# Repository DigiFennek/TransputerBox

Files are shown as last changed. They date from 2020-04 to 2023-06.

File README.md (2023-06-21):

# TransputerBox
This is the DosBox based TransputerBox

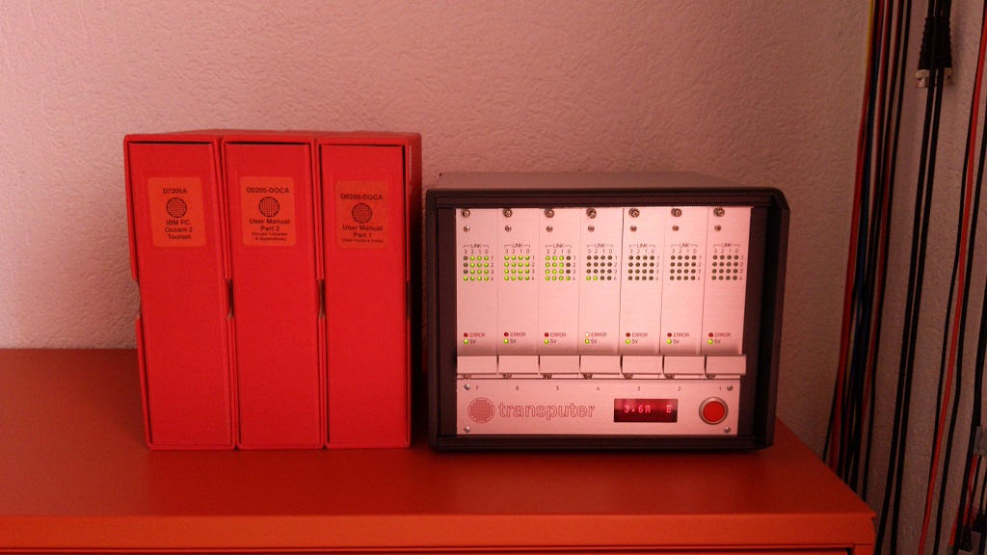
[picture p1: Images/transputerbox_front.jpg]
TransputerBox Front


The interface is based on a LPC dual-core MPU. The Cortex-M4 is doing USB stuff while the Cortex-M0+ is talking to the IMSC012 Transpuer Link Interface. The MCU is also checking the health status of the power supply and the cooling system.

The host-side is based on a modified version of DOSBox. It emulates the IMSB008 or IMSB004 hardware and connets to the TransputerBox via USB.

Software:
  - DOSBox with USB-Bridge, Windows 10, Visual Studio 2019: [Link](https://github.com/DigiFennek/TransputerBox/tree/master/Visual%20Studio)
  - USB-Interface, based on NXP's LPC54114, MCUXPresso IDE v11: [Link](https://github.com/DigiFennek/TransputerBox/tree/master/MCUXpresso)
  - CPLD for the fancy Link-Leds, Lattice M4A5-64/32-10VC, ispLever Classic: [Link](https://github.com/DigiFennek/TransputerBox/tree/master/ispLEVER%20Classic/linkled)
  
Hardware:
  - Module for 4 TRAM's, Eagle Layout Editor: [Link](https://github.com/DigiFennek/TransputerBox/tree/master/Eagle/TB-4)
  - Backpanel with 7 slots, Eagle Layout Editor: [Link](https://github.com/DigiFennek/TransputerBox/tree/master/Eagle/BB-7)
  - USB Interface with Power Management, Current Sensor and HP-Display, Eagle Layout Editor: [Link](https://github.com/DigiFennek/TransputerBox/tree/master/Eagle/UB-1)
  - SIZE-1 TRAM with 128kB SRAM, Eagle Layout Editor: [Link](https://github.com/DigiFennek/TransputerBox/tree/master/Eagle/TM-2)    
  
Misc
  - Front Panels, www.schaeffer-ag.de "FRONTPLATTEN DESIGNER": [Link](https://github.com/DigiFennek/TransputerBox/tree/master/Schaeffer%20AG)

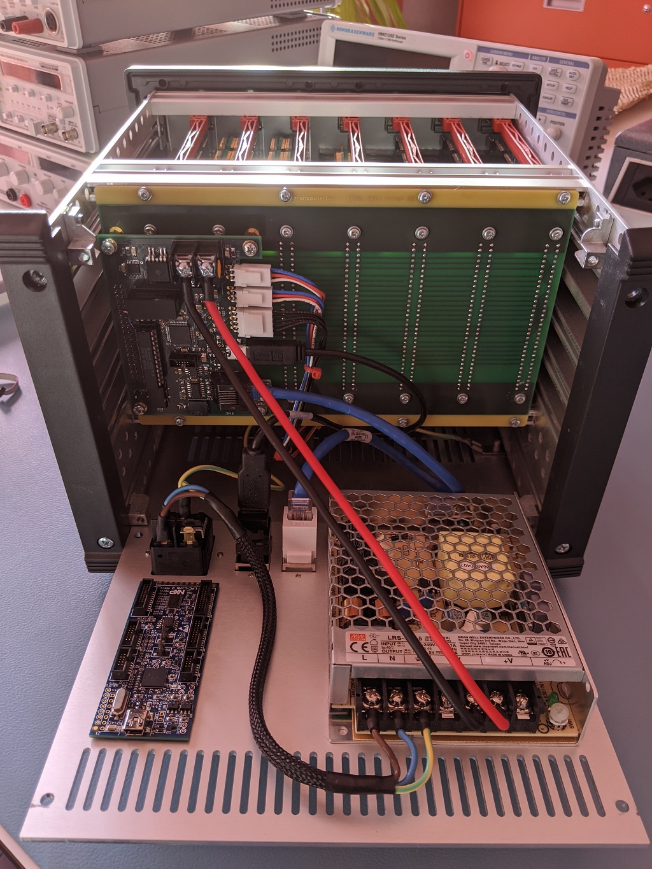
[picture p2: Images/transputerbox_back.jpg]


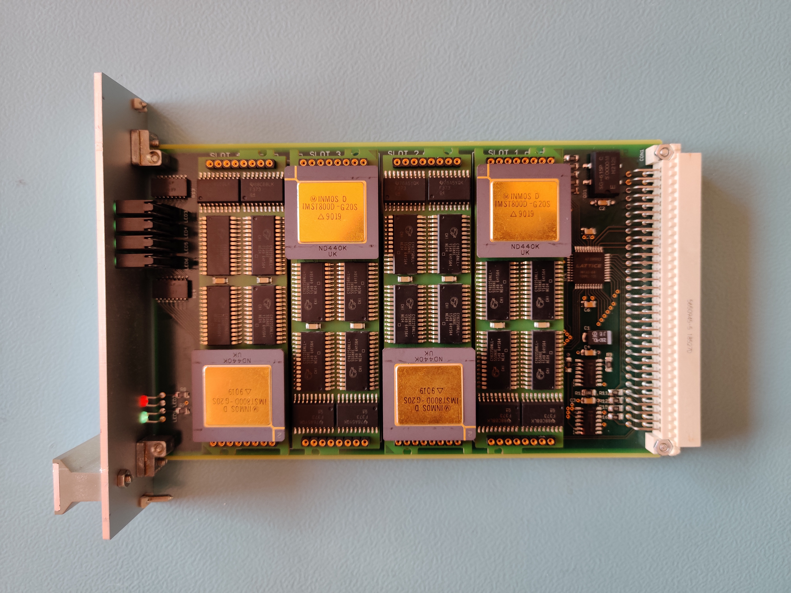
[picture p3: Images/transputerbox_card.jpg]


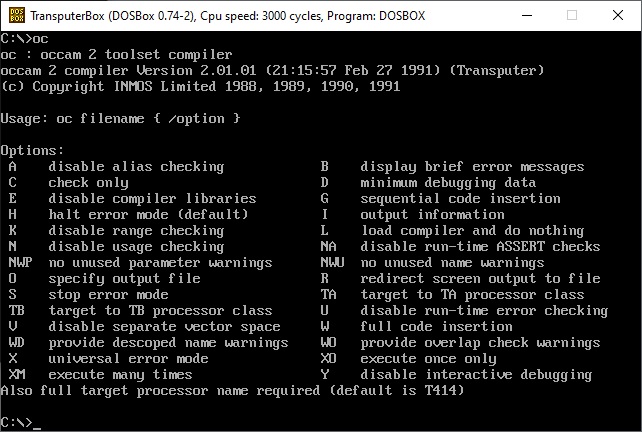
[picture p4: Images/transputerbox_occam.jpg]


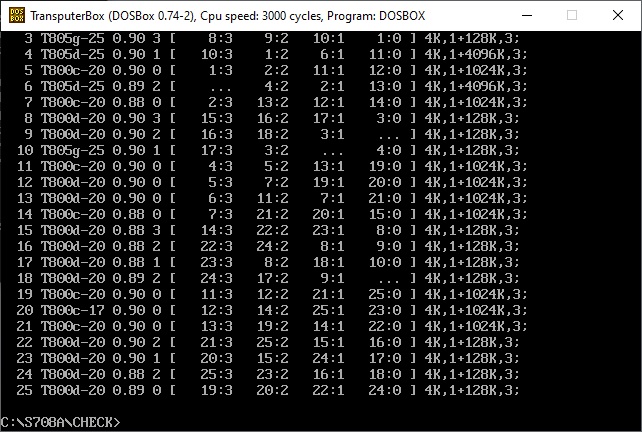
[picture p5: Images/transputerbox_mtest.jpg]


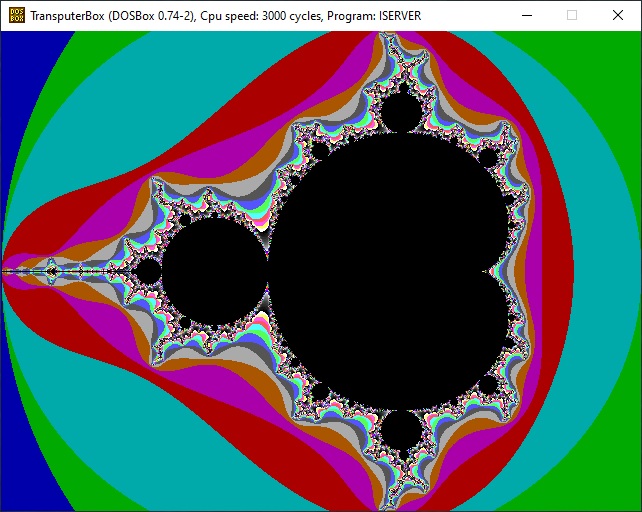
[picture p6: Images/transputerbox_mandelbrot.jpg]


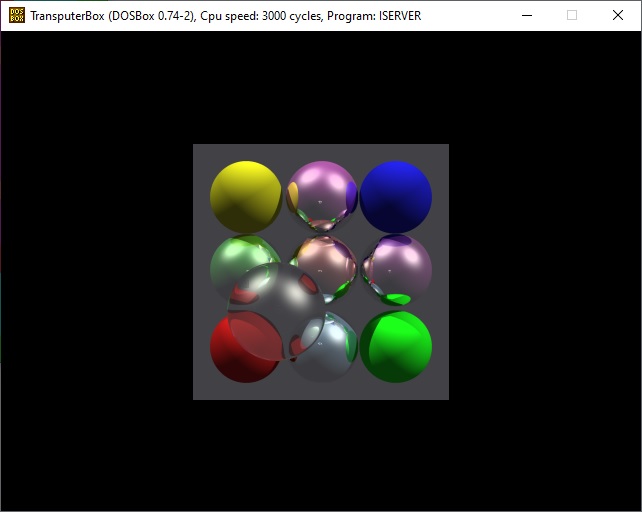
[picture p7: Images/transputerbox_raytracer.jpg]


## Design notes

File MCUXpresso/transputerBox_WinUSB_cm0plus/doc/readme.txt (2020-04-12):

Overview
========
The Multicore Hello World demo application demonstrates how to set up projects for individual
cores on a multicore system. In this demo, the primary core prints the "Hello World from the Primary Core!"
string to the terminal and then releases the secondary core from the reset. The secondary
core toggles an on-board LED indicating that the secondary core is running.

Toolchain supported
===================
- IAR embedded Workbench  8.32.3
- MCUXpresso  11.0.0
- GCC ARM Embedded  8.2.1
- Keil MDK  5.27

Hardware requirements
=====================
- Mini/micro USB cable
- LPCXpresso54114 board
- Personal Computer

Board settings
==============
No special settings are required.

Prepare the Demo
================
1.  Connect a micro USB cable between the PC host and the CMSIS DAP USB port (J7) on the board
2.  Open a serial terminal with the following settings (See Appendix A in Getting started guide for description how to determine serial port number):
    - 115200 baud rate
    - 8 data bits
    - No parity
    - One stop bit
    - No flow control
3.  Download the program to the target board.
4.  Either press the reset button on your board or launch the debugger in your IDE to begin running the demo.

Running the demo
================
The log below shows the output of the hello world multicore demo in the terminal window:
~~~~~~~~~~~~~~~~~~~~~~~~~~~~~~~~~~~
Copy Secondary core image to address: 0x20010000, size: 3280
Starting Secondary core.

Hello World from the Primary Core!

Starting Secondary core.
The secondary core application has been started.

~~~~~~~~~~~~~~~~~~~~~~~~~~~~~~~~~~~
Customization options
=====================

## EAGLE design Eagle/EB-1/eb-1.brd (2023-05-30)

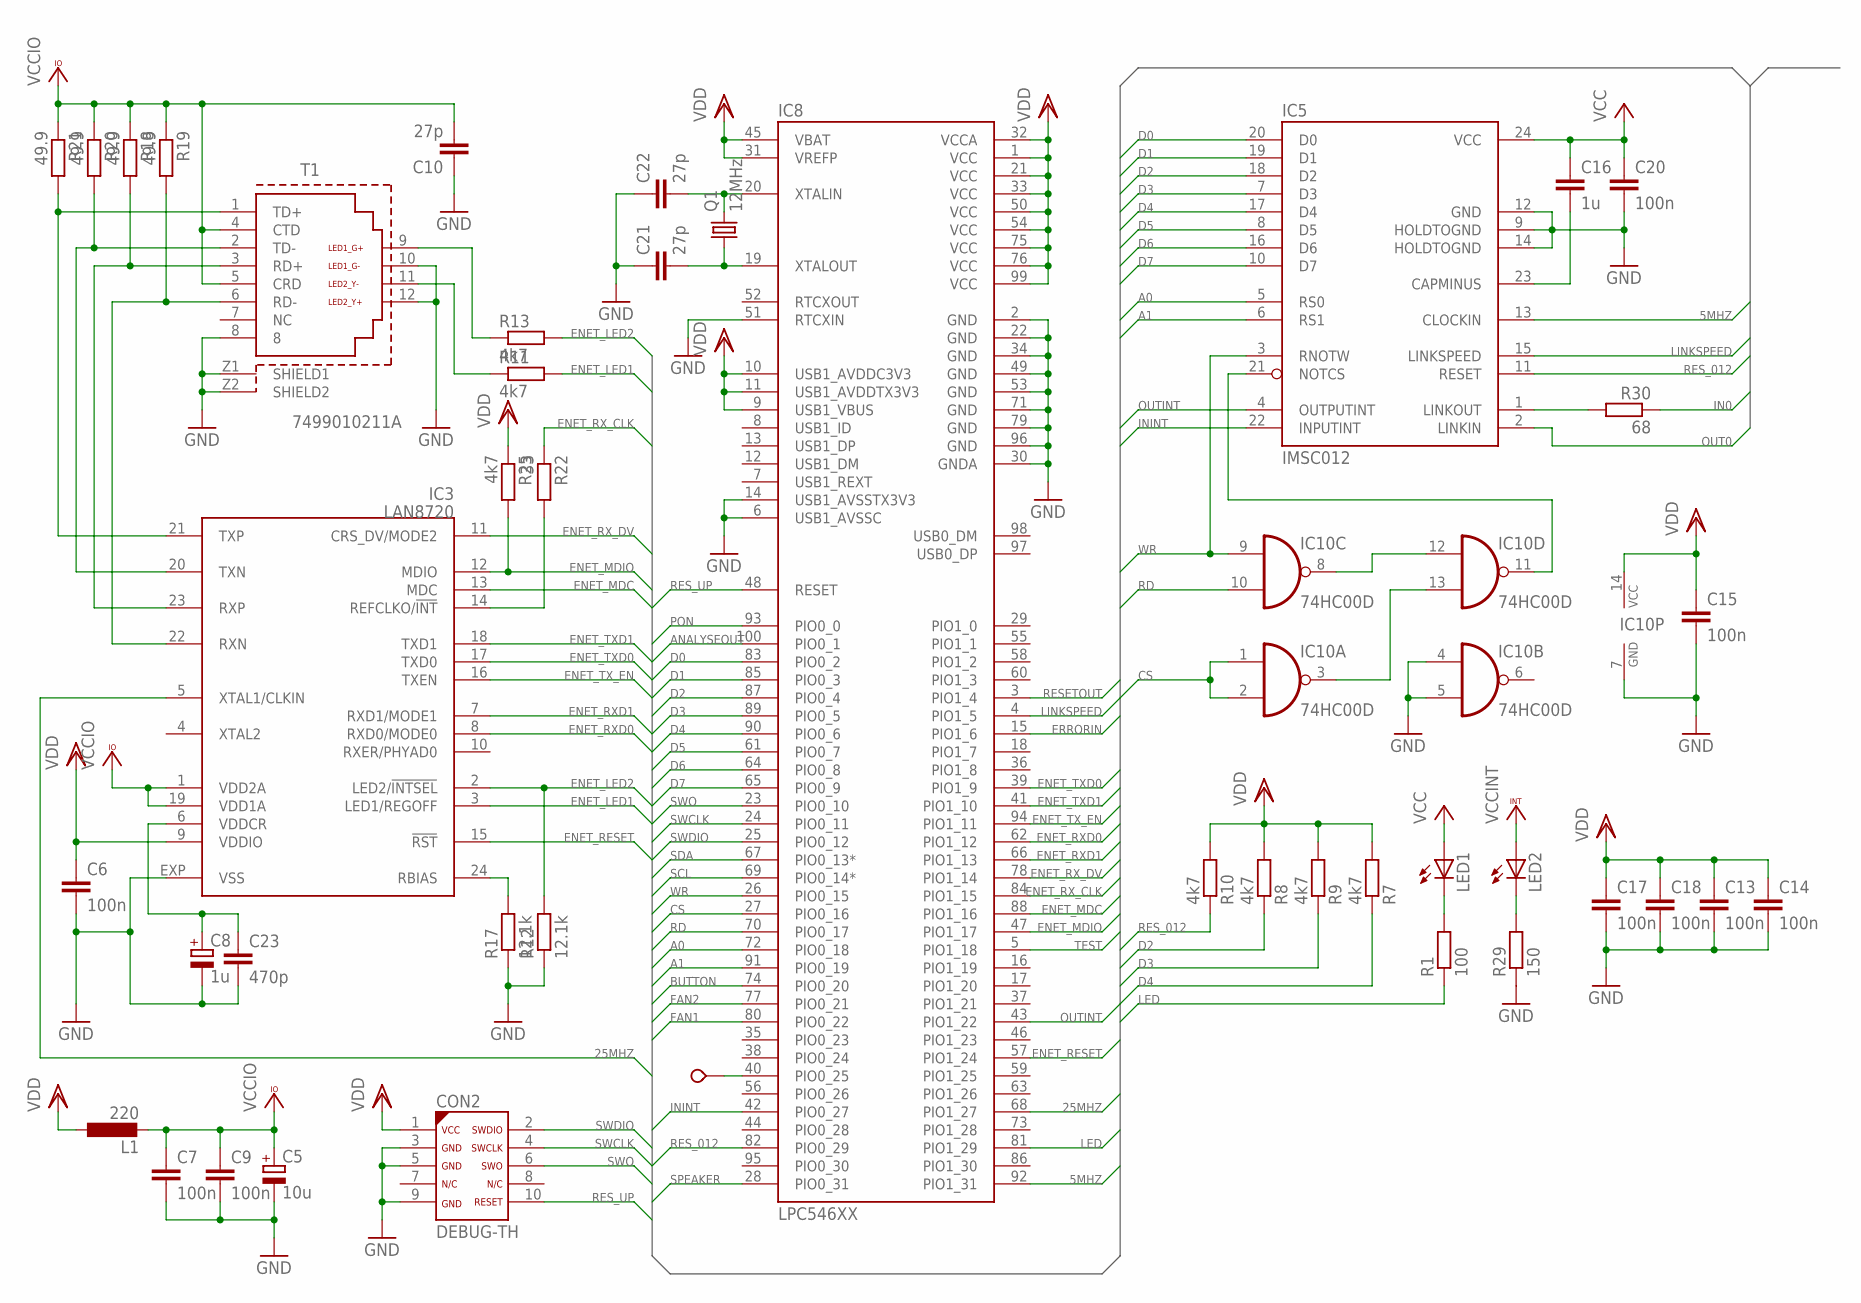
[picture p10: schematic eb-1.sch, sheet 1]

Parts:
C5: 10u; CT3216
C6, C7, C9, C13, C14, C15, C17, C18, C20: 100n; C1206; DIGIKEY 478-10855-1-ND
C8: 1u; CT3216
C10, C21, C22: 27p; C1206; DIGIKEY 478-10855-1-ND
C16: 1u; C1206; DIGIKEY 478-1567-1-ND
C23: 470p; C1206; DIGIKEY 478-10855-1-ND
CON2: DEBUG-TH; DIGIKEY 1175-1627-ND
IC3: LAN8720; QFN24
IC5: IMSC012; DIL24-3
IC8: LPC546XX; LQFP100
IC10: 74HC00D; SO14
L1: 220; L3216C
LED1, LED2: LEDSMT1206; 1206; DIGIKEY 160-1404-1-ND
Q1: 12MHz; HC49UP
R1: 100; R1206; DIGIKEY CR1206-FX-1000ELFCT-ND
R7, R8, R9, R10, R11, R13, R25: 4k7; R1206; DIGIKEY CR1206-FX-4701ELFCT-ND
R12, R17: 12.1k; R1206; DIGIKEY CR1206-FX-4701ELFCT-ND
R18, R19, R20, R21: 49.9; R1206; DIGIKEY CR1206-FX-4701ELFCT-ND
R22: 33; R1206; DIGIKEY CR1206-FX-4701ELFCT-ND
R29: 150; R1206; DIGIKEY CR1206-FX-1500ELFCT-ND
R30: 68; R1206; DIGIKEY CR1206-FX-68R0ELFCT-ND
T1: 7499010211A
TP2: TESTPOINT; VERO_TP

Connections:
5MHZ: IC5.13 (CLOCKIN), IC8.92 (PIO1_31)
25MHZ: IC3.5 (XTAL1/CLKIN), IC8.68 (PIO1_27)
A0: IC5.5 (RS0), IC8.72 (PIO0_18)
A1: IC5.6 (RS1), IC8.91 (PIO0_19)
ANALYSEOUT: IC8.100 (PIO0_1); also elsewhere on the board
BUTTON: IC8.74 (PIO0_20); also elsewhere on the board
CS: IC8.27 (PIO0_16), IC10.1 (I0), IC10.2 (I1)
D0: IC5.20 (D0), IC8.83 (PIO0_2)
D1: IC5.19 (D1), IC8.85 (PIO0_3)
D2: IC5.18 (D2), IC8.87 (PIO0_4), R8.1
D3: IC5.7 (D3), IC8.89 (PIO0_5), R9.1
D4: IC5.17 (D4), IC8.90 (PIO0_6), R7.1
D5: IC5.8 (D5), IC8.61 (PIO0_7)
D6: IC5.16 (D6), IC8.64 (PIO0_8)
D7: IC5.10 (D7), IC8.65 (PIO0_9)
ENET_LED1: IC3.3 (LED1/REGOFF), R11.2
ENET_LED2: IC3.2 (LED2/!INTSEL), R12.2, R13.2
ENET_MDC: IC3.13 (MDC), IC8.88 (PIO1_16)
ENET_MDIO: IC3.12 (MDIO), IC8.47 (PIO1_17), R25.2
ENET_RESET: IC3.15 (!RST), IC8.57 (PIO1_24)
ENET_RXD0: IC3.8 (RXD0/MODE0), IC8.62 (PIO1_12)
ENET_RXD1: IC3.7 (RXD1/MODE1), IC8.66 (PIO1_13)
ENET_RX_CLK: IC8.84 (PIO1_15), R22.1
ENET_RX_DV: IC3.11 (CRS_DV/MODE2), IC8.78 (PIO1_14)
ENET_TXD0: IC3.17 (TXD0), IC8.39 (PIO1_9)
ENET_TXD1: IC3.18 (TXD1), IC8.41 (PIO1_10)
ENET_TX_EN: IC3.16 (TXEN), IC8.94 (PIO1_11)
ERRORIN: IC8.15 (PIO1_6); also elsewhere on the board
FAN1: IC8.80 (PIO0_22); also elsewhere on the board
FAN2: IC8.77 (PIO0_21); also elsewhere on the board
GND: C5.-, C6.2, C7.2, C8.-, C9.2, C10.1, C13.2, C14.2, C15.2, C17.2, C18.2, C20.2, C21.1, C22.1, C23.2, CON2.3, CON2.5, CON2.9, IC3.EXP (VSS), IC5.9 (HOLDTOGND), IC5.12 (GND), IC5.14 (HOLDTOGND), IC8.2 (GND), IC8.6 (USB1_AVSSC), IC8.14 (USB1_AVSSTX3V3), IC8.22 (GND), IC8.30 (GNDA), IC8.34 (GND), IC8.49 (GND), IC8.51 (RTCXIN), IC8.53 (GND), IC8.71 (GND), IC8.79 (GND), IC8.96 (GND), IC10.4 (I0), IC10.5 (I1), IC10.7 (GND), R12.1, R17.1, R29.1, T1.8, T1.10 (LED1_G-), T1.12 (LED2_Y+), T1.Z1 (SHIELD1), T1.Z2 (SHIELD2); also elsewhere on the board
IN0: R30.1; also elsewhere on the board
ININT: IC5.22 (INPUTINT), IC8.42 (PIO0_27)
LED: IC8.81 (PIO1_29), R1.1
LINKSPEED: IC5.15 (LINKSPEED), IC8.4 (PIO1_5); also elsewhere on the board
unnamed: IC3.14 (REFCLKO/!INT), R22.2
unnamed: R13.1, T1.9 (LED1_G+)
unnamed: IC3.24 (RBIAS), R17.2
unnamed: R11.1, T1.11 (LED2_Y-)
unnamed: IC8.40 (PIO0_25), TP2.P$1
unnamed: C8.+, C23.1, IC3.6 (VDDCR)
unnamed: C22.2, IC8.20 (XTALIN), Q1.2
unnamed: C21.2, IC8.19 (XTALOUT), Q1.1
unnamed: IC5.1 (LINKOUT), R30.2
unnamed: IC5.21 (NOTCS), IC10.11 (O)
unnamed: C16.2, IC5.23 (CAPMINUS)
unnamed: LED2.C, R29.2
unnamed: LED1.C, R1.2
unnamed: IC10.8 (O), IC10.12 (I0)
unnamed: IC10.3 (O), IC10.13 (I1)
OUT0: IC5.2 (LINKIN); also elsewhere on the board
OUTINT: IC5.4 (OUTPUTINT), IC8.43 (PIO1_22)
PON: IC8.93 (PIO0_0); also elsewhere on the board
RD: IC8.70 (PIO0_17), IC10.10 (I1)
RESETOUT: IC8.3 (PIO1_4); also elsewhere on the board
RES_012: IC5.11 (RESET), IC8.82 (PIO0_29), R10.1
RES_UP: CON2.10, IC8.48 (RESET)
RX_N: IC3.22 (RXN), R19.2, T1.6 (RD-)
RX_P: IC3.23 (RXP), R18.2, T1.3 (RD+)
SCL: IC8.69 (PIO0_14*); also elsewhere on the board
SDA: IC8.67 (PIO0_13*); also elsewhere on the board
SPEAKER: IC8.28 (PIO0_31); also elsewhere on the board
SWCLK: CON2.4, IC8.24 (PIO0_11)
SWDIO: CON2.2, IC8.25 (PIO0_12)
SWO: CON2.6, IC8.23 (PIO0_10)
TEST: IC8.5 (PIO1_18); also elsewhere on the board
TX_N: IC3.20 (TXN), R20.2, T1.2 (TD-)
TX_P: IC3.21 (TXP), R21.2, T1.1 (TD+)
VCC: C16.1, C20.1, IC5.24 (VCC), LED1.A; also elsewhere on the board
VCCINT: LED2.A; also elsewhere on the board
VCCIO: C5.+, C7.1, C9.1, C10.2, IC3.1 (VDD2A), IC3.19 (VDD1A), L1.2, R18.1, R19.1, R20.1, R21.1, T1.4 (CTD), T1.5 (CRD)
VDD: C6.1, C13.1, C14.1, C15.1, C17.1, C18.1, CON2.1, IC3.9 (VDDIO), IC8.1 (VCC), IC8.9 (USB1_VBUS), IC8.10 (USB1_AVDDC3V3), IC8.11 (USB1_AVDDTX3V3), IC8.21 (VCC), IC8.31 (VREFP), IC8.32 (VCCA), IC8.33 (VCC), IC8.45 (VBAT), IC8.50 (VCC), IC8.54 (VCC), IC8.75 (VCC), IC8.76 (VCC), IC8.99 (VCC), IC10.14 (VCC), L1.1, R7.2, R8.2, R9.2, R10.2, R25.1; also elsewhere on the board
WR: IC5.3 (RNOTW), IC8.26 (PIO0_15), IC10.9 (I0)

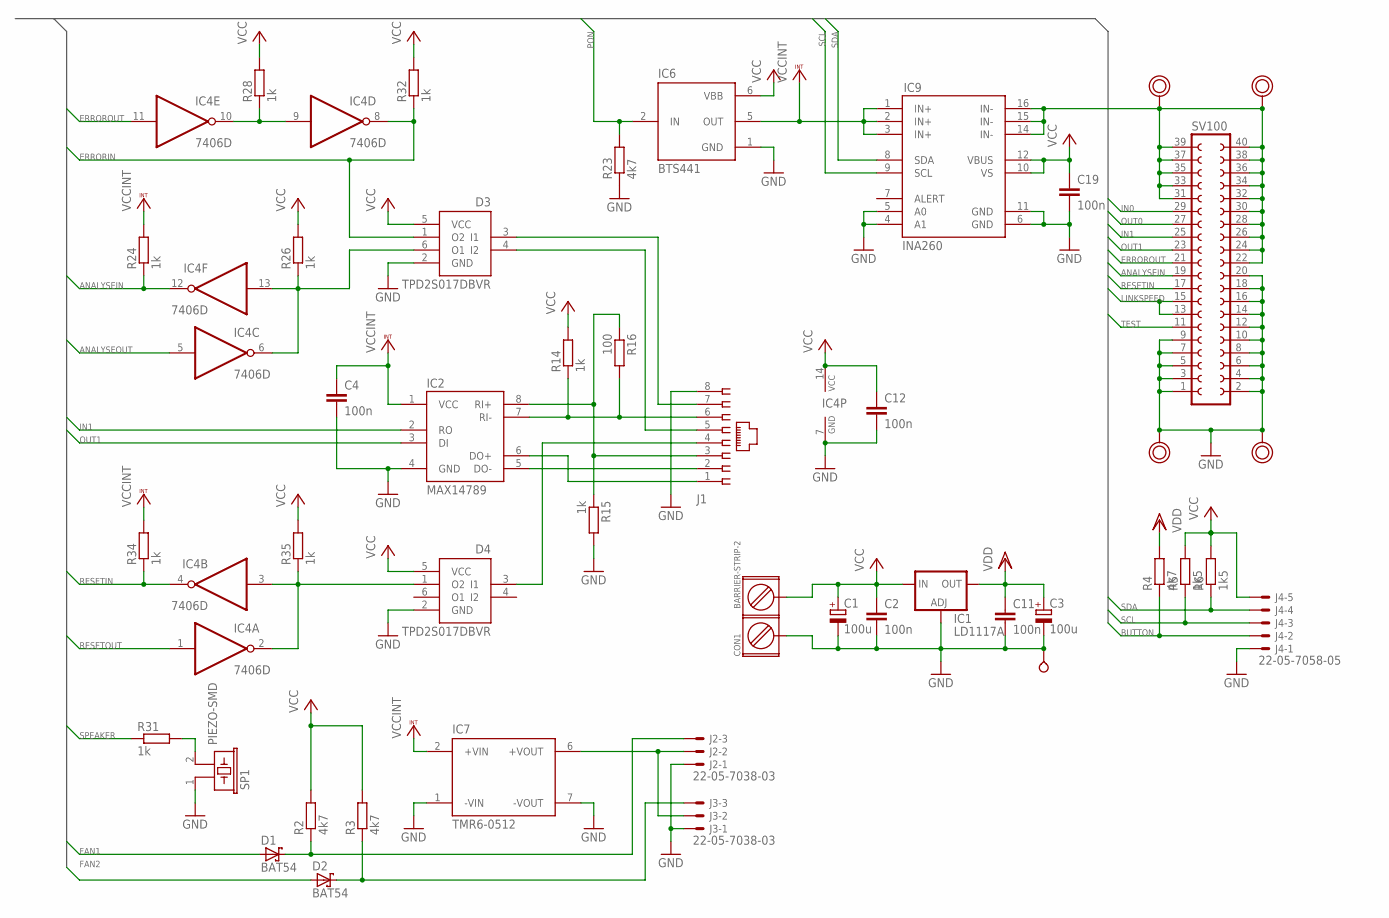
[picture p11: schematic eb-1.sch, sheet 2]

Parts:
C1, C3: 100u; SMC_B; DIGIKEY 478-5801-1-ND
C2, C4, C11, C12, C19: 100n; C1206; DIGIKEY 478-10855-1-ND
CON1: BARRIER-STRIP-2; DIGIKEY WM13929-ND
D1, D2: BAT54; SOT23; DIGIKEY BAT54FSCT-ND
D3, D4: TPD2S017DBVR; SOT23-6
IC1: LD1117A; SOT223; DIGIKEY 497-1228-1-ND
IC2: MAX14789; SO8; DIGIKEY MAX14789EGSA+-ND
IC4: 7406D; SO14
IC6: BTS441; TO263-4; DIGIKEY BTS441TGATMA1CT-ND
IC7: TMR6-0512; DIGIKEY 1951-2391-ND
IC9: INA260; TSSOP-16; DIGIKEY 296-47777-1-ND
J1: 555164-1; DIGIKEY A31442-ND
J2, J3: 22-05-7038-03; 7395-03; DIGIKEY WM2785-ND
J4: 22-05-7058-05; 7395-05; DIGIKEY WM2787-ND
R2, R3, R4, R23: 4k7; R1206; DIGIKEY CR1206-FX-4701ELFCT-ND
R5, R6: 1k5; R1206; DIGIKEY CR1206-FX-1501ELFCT-ND
R14, R15, R24, R26, R28, R31, R32, R34, R35: 1k; R1206; DIGIKEY CR1206-FX-1001ELFCT-ND
R16: 100; R1206; DIGIKEY CR1206-FX-1000ELFCT-ND
SCREW1, SCREW2, SCREW3, SCREW4: POWERPAD
SP1: PIEZO-SMD; DIGIKEY 490-9647-1-ND
SV100: FE20-2
TP1: TESTPOINT; VERO_TP

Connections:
ANALYSEIN: IC4.12 (O), R24.1, SV100.19
ANALYSEOUT: IC4.5 (I); also elsewhere on the board
BUTTON: J4.2, R4.1; also elsewhere on the board
ERRORIN: D3.1 (O2), IC4.8 (O), R32.1; also elsewhere on the board
ERROROUT: IC4.11 (I), SV100.21
FAN1: D1.1 (A); also elsewhere on the board
FAN2: D2.1 (A); also elsewhere on the board
GND: C1.-, C2.2, C3.-, C4.2, C11.2, C12.2, C19.2, CON1.1, D3.2 (GND), D4.2 (GND), IC1.1 (ADJ), IC2.4 (GND), IC4.7 (GND), IC6.1 (GND), IC7.1 (-VIN), IC7.7 (-VOUT), IC9.4 (A1), IC9.5 (A0), IC9.6 (GND), IC9.11 (GND), J1.8, J2.1, J3.1, J4.1, R15.2, R23.1, SCREW2.P$1, SCREW4.P$1, SP1.1, SV100.1, SV100.2, SV100.3, SV100.4, SV100.5, SV100.6, SV100.7, SV100.8, SV100.9, SV100.10, SV100.12, SV100.14, SV100.16, SV100.18, SV100.20, TP1.P$1; also elsewhere on the board
IN0: SV100.29; also elsewhere on the board
IN1: IC2.2 (RO), SV100.25
LINKSPEED: SV100.13, SV100.15; also elsewhere on the board
unnamed: D4.1 (O2), IC4.2 (O), IC4.3 (I), R35.1
unnamed: IC4.9 (I), IC4.10 (O), R28.1
unnamed: IC2.6 (DO+), J1.1
unnamed: IC2.5 (DO-), J1.2
unnamed: D3.3 (I1), J1.7
unnamed: D4.3 (I1), J1.4
unnamed: D3.4 (I2), J1.5
unnamed: D3.6 (O1), IC4.6 (O), IC4.13 (I), R26.1
unnamed: IC2.8 (RI+), J1.3, R15.1, R16.1
unnamed: IC2.7 (RI-), J1.6, R14.1, R16.2
unnamed: D2.3 (C), J3.3, R3.1
unnamed: IC9.14 (IN-), IC9.15 (IN-), IC9.16 (IN-), SCREW1.P$1, SCREW3.P$1, SV100.22, SV100.24, SV100.26, SV100.28, SV100.30, SV100.31, SV100.32, SV100.33, SV100.34, SV100.35, SV100.36, SV100.37, SV100.38, SV100.39, SV100.40
unnamed: D1.3 (C), J2.3, R2.1
unnamed: R31.2, SP1.2
unnamed: IC7.6 (+VOUT), J2.2, J3.2
OUT0: SV100.27; also elsewhere on the board
OUT1: IC2.3 (DI), SV100.23
PON: IC6.2 (IN), R23.2; also elsewhere on the board
RESETIN: IC4.4 (O), R34.1, SV100.17
RESETOUT: IC4.1 (I); also elsewhere on the board
SCL: IC9.9 (SCL), J4.4, R6.1; also elsewhere on the board
SDA: IC9.8 (SDA), J4.3, R5.1; also elsewhere on the board
SPEAKER: R31.1; also elsewhere on the board
TEST: SV100.11; also elsewhere on the board
VCC: C1.+, C2.1, C12.1, C19.1, CON1.2, D3.5 (VCC), D4.5 (VCC), IC1.3 (IN), IC4.14 (VCC), IC6.6 (VBB), IC9.10 (VS), IC9.12 (VBUS), J4.5, R2.2, R3.2, R5.2, R6.2, R14.2, R26.2, R28.2, R32.2, R35.2; also elsewhere on the board
VCCINT: C4.1, IC2.1 (VCC), IC6.5 (OUT), IC7.2 (+VIN), IC9.1 (IN+), IC9.2 (IN+), IC9.3 (IN+), R24.2, R34.2; also elsewhere on the board
VDD: C3.+, C11.1, IC1.2 (OUT), R4.2; also elsewhere on the board

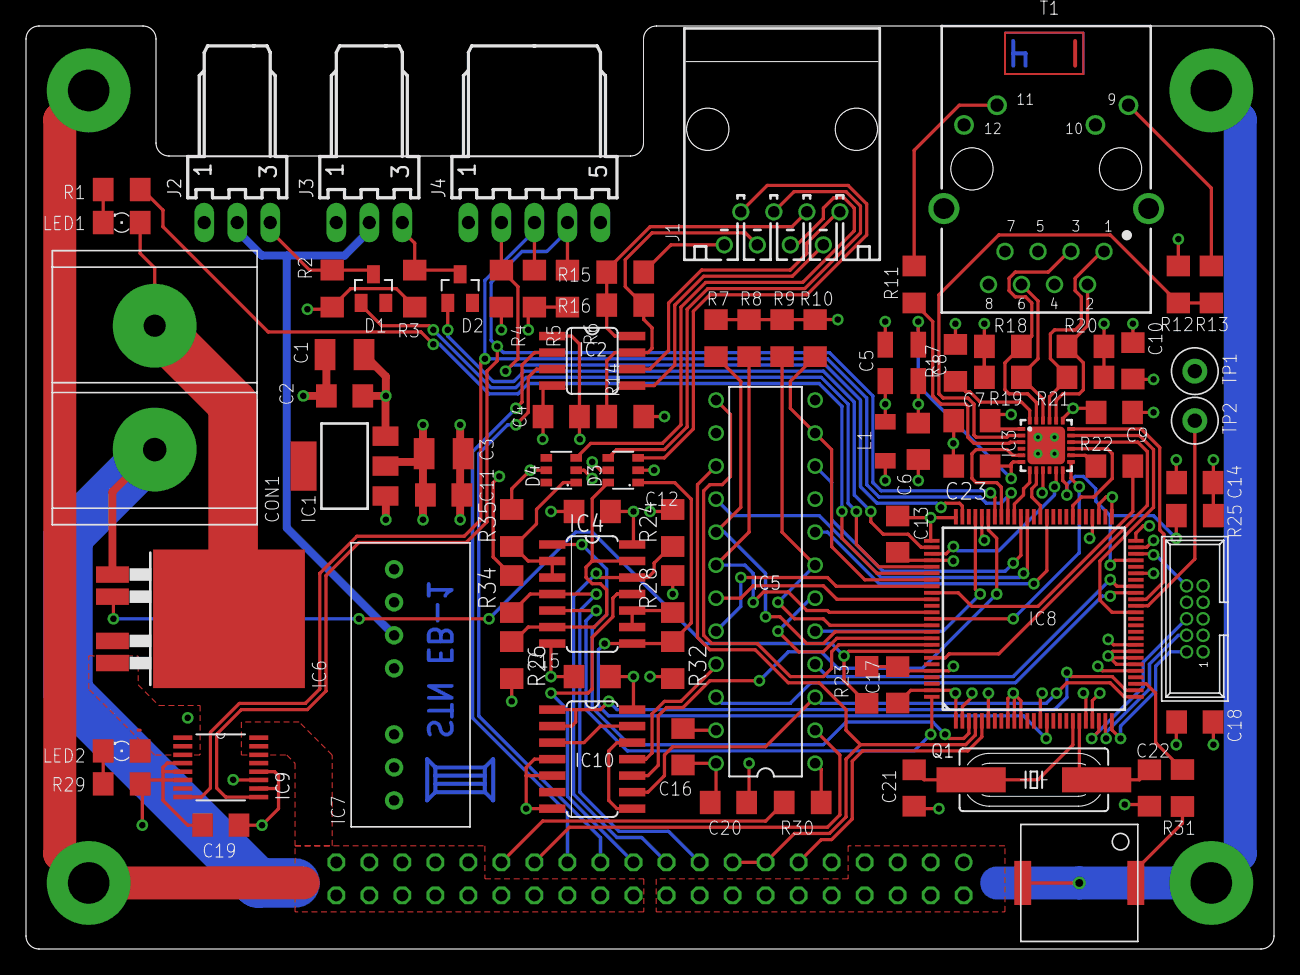
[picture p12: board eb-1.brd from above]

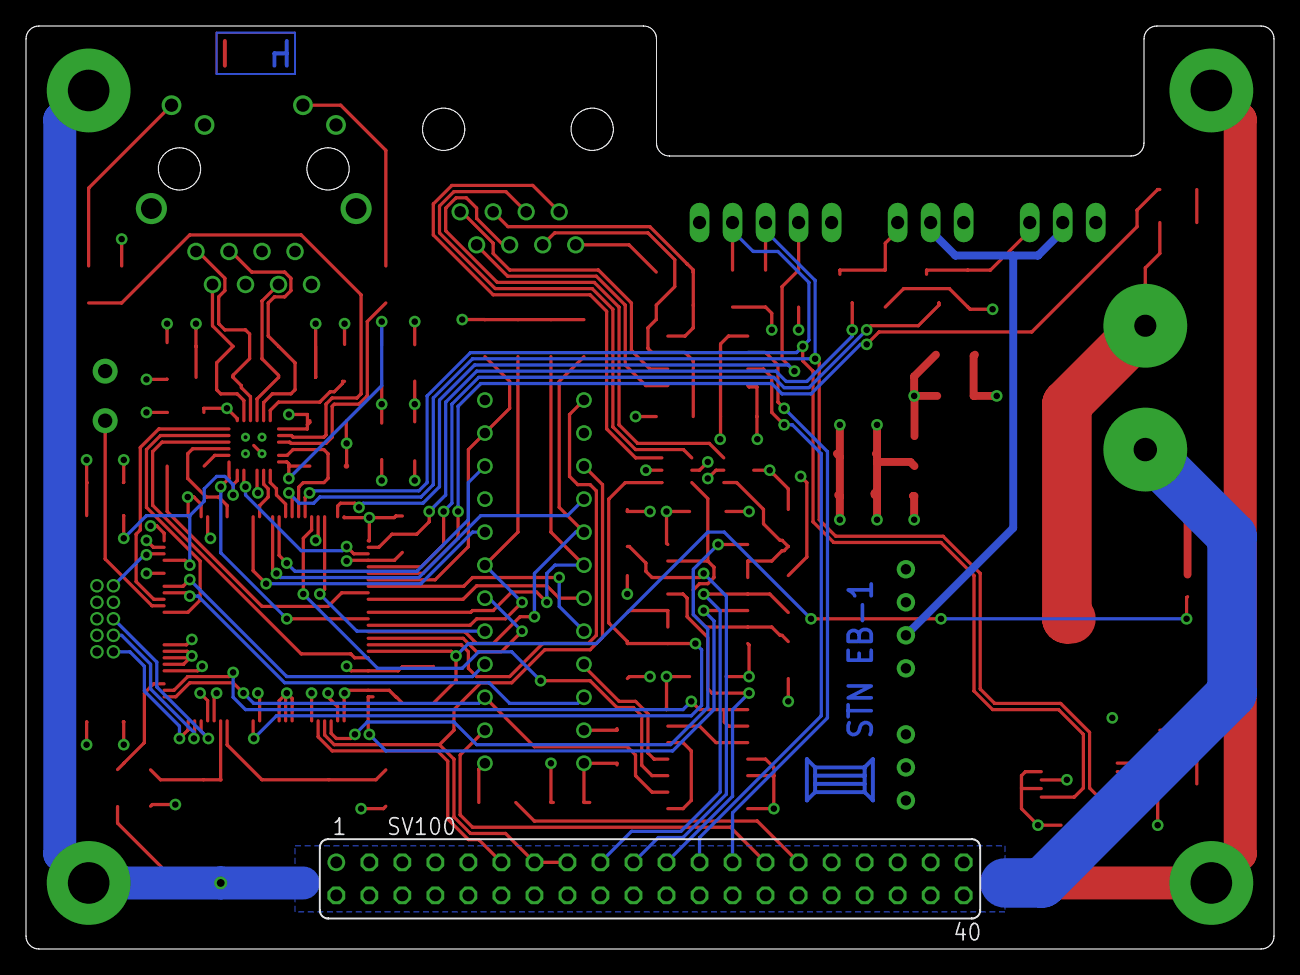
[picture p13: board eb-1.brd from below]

Board: 6 copper layers, 96.0 x 71.0 mm, 91 parts (2 on the bottom side), 93 nets.

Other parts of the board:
U$1: LAYER14
U$100: LOGO

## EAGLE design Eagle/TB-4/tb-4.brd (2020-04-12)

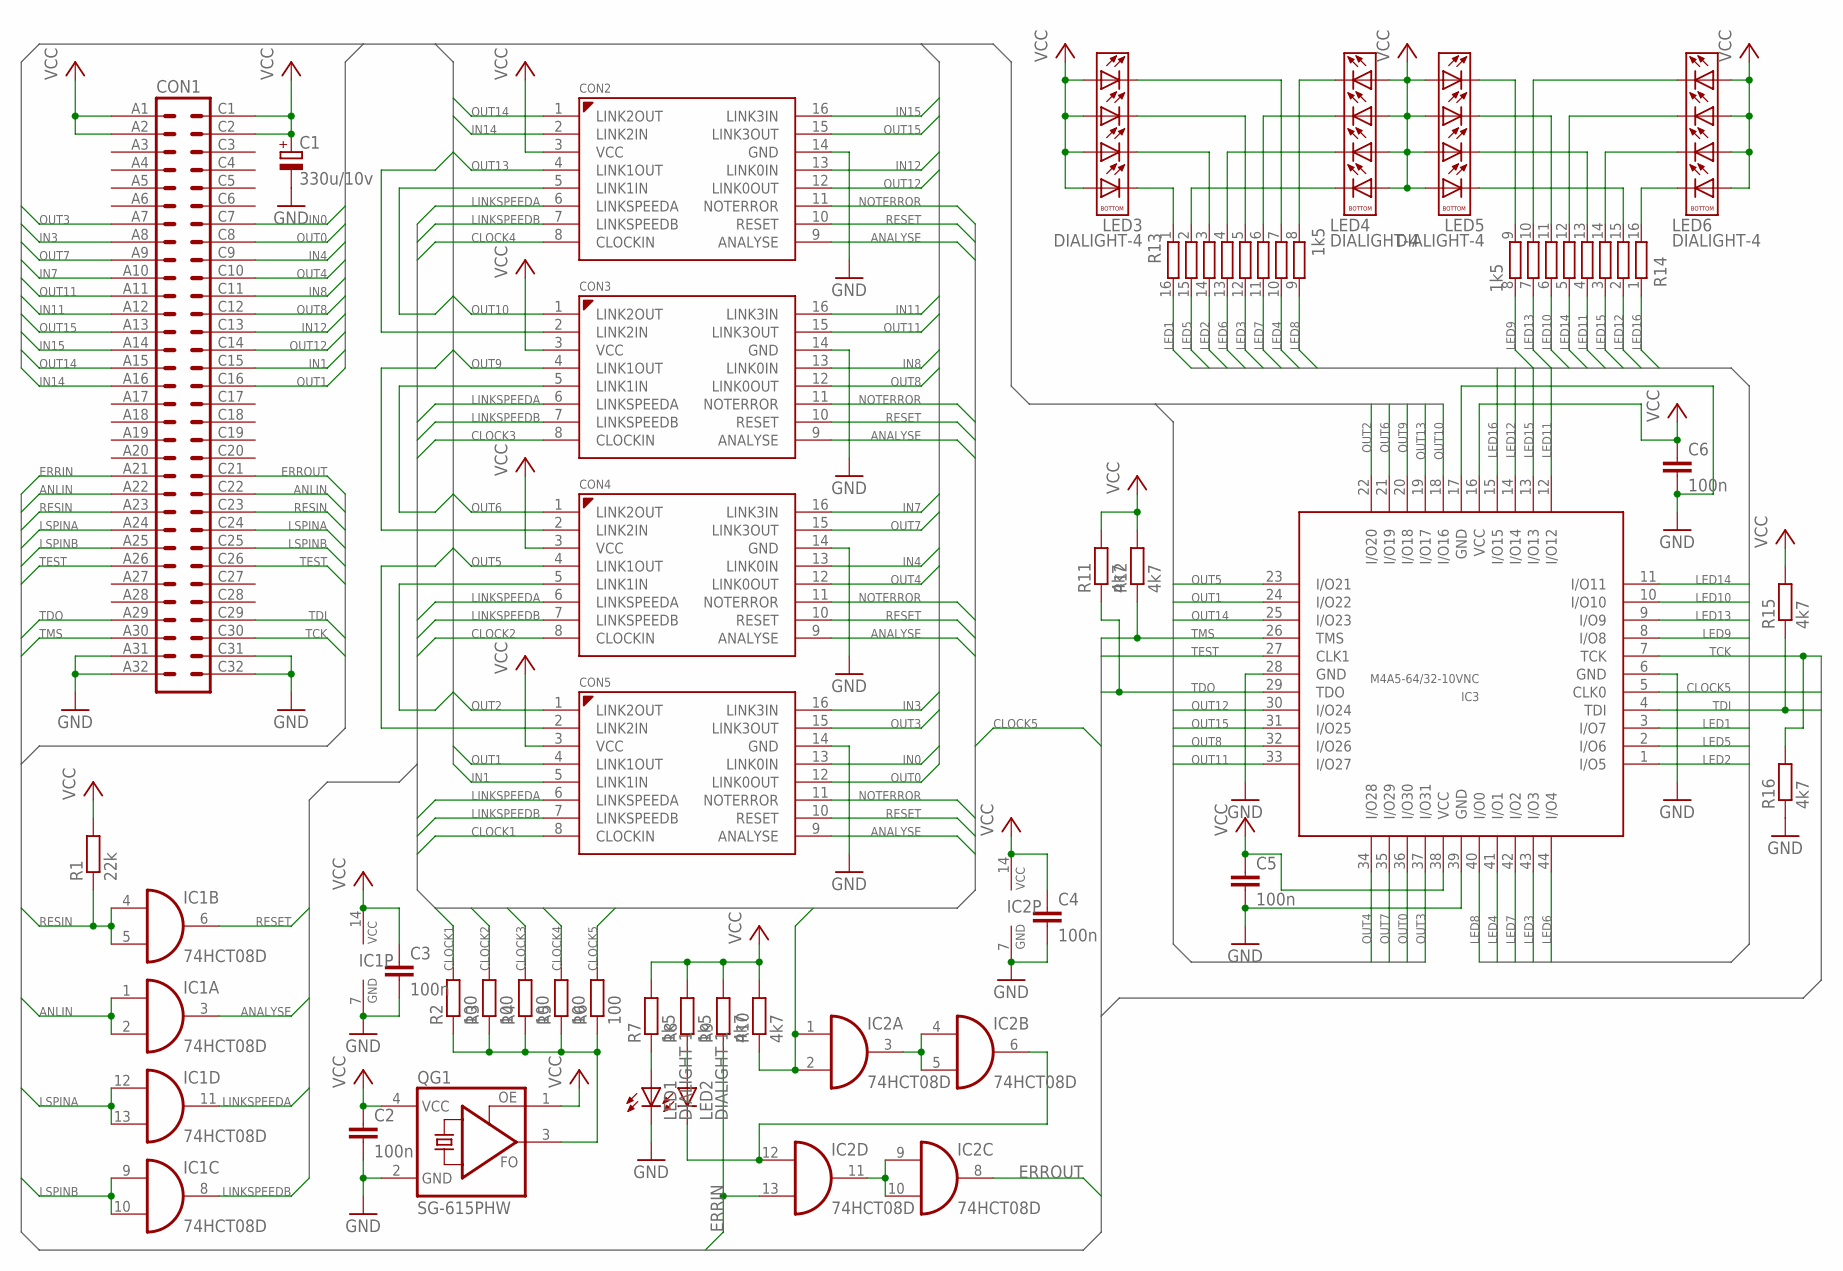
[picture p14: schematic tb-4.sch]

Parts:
C1: 330u/10v; SMC_E
C2, C3, C4, C5, C6: 100n; C1206
CON1: HARTING 09 03 164 6921; EUROPAKARTE-TB4
CON2, CON3, CON4, CON5: TRAM-1; TRAM-1-MB
IC1, IC2: 74HCT08D; SO14
IC3: M4A5-64/32-10VNC; TQFP-44
LED1, LED2: DIALIGHT-1
LED3, LED4, LED5, LED6: DIALIGHT-4
QG1: SG-615PHW; SG-615
R1: 22k; R1206
R2, R3, R4, R5, R6: 100; R1206
R7, R8: 1k5; R1206
R9, R10, R11, R12, R15, R16: 4k7; R1206
R13, R14: 1k5; 4816P

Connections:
ANALYSE: CON2.9 (ANALYSE), CON3.9 (ANALYSE), CON4.9 (ANALYSE), CON5.9 (ANALYSE), IC1.3 (O)
ANLIN: CON1.A22, CON1.C22, IC1.1 (I0), IC1.2 (I1)
CLOCK1: CON5.8 (CLOCKIN), R2.2
CLOCK2: CON4.8 (CLOCKIN), R3.2
CLOCK3: CON3.8 (CLOCKIN), R4.2
CLOCK4: CON2.8 (CLOCKIN), R5.2
CLOCK5: IC3.5 (CLK0), R6.2
ERRIN: CON1.A21, IC2.13 (I1), R9.1
ERROUT: CON1.C21, IC2.8 (O)
GND: C1.-, C2.2, C3.2, C4.2, C5.2, C6.2, CON1.A31, CON1.A32, CON1.C31, CON1.C32, CON2.14 (GND), CON3.14 (GND), CON4.14 (GND), CON5.14 (GND), IC1.7 (GND), IC2.7 (GND), IC3.6 (GND), IC3.17 (GND), IC3.28 (GND), IC3.39 (GND), LED1.C1 (C), QG1.2 (GND), R16.1
IN0: CON1.C7, CON5.13 (LINK0IN)
IN1: CON1.C15, CON5.5 (LINK1IN)
IN3: CON1.A8, CON5.16 (LINK3IN)
IN4: CON1.C9, CON4.13 (LINK0IN)
IN7: CON1.A10, CON4.16 (LINK3IN)
IN8: CON1.C11, CON3.13 (LINK0IN)
IN11: CON1.A12, CON3.16 (LINK3IN)
IN12: CON1.C13, CON2.13 (LINK0IN)
IN14: CON1.A16, CON2.2 (LINK2IN)
IN15: CON1.A14, CON2.16 (LINK3IN)
LED1: IC3.3 (I/O7), R13.16
LED2: IC3.1 (I/O5), R13.14
LED3: IC3.43 (I/O3), R13.12
LED4: IC3.41 (I/O1), R13.10
LED5: IC3.2 (I/O6), R13.15
LED6: IC3.44 (I/O4), R13.13
LED7: IC3.42 (I/O2), R13.11
LED8: IC3.40 (I/O0), R13.9
LED9: IC3.8 (I/O8), R14.8
LED10: IC3.10 (I/O10), R14.6
LED11: IC3.12 (I/O12), R14.4
LED12: IC3.14 (I/O14), R14.2
LED13: IC3.9 (I/O9), R14.7
LED14: IC3.11 (I/O11), R14.5
LED15: IC3.13 (I/O13), R14.3
LED16: IC3.15 (I/O15), R14.1
LINKSPEEDA: CON2.6 (LINKSPEEDA), CON3.6 (LINKSPEEDA), CON4.6 (LINKSPEEDA), CON5.6 (LINKSPEEDA), IC1.11 (O)
LINKSPEEDB: CON2.7 (LINKSPEEDB), CON3.7 (LINKSPEEDB), CON4.7 (LINKSPEEDB), CON5.7 (LINKSPEEDB), IC1.8 (O)
LSPINA: CON1.A24, CON1.C24, IC1.12 (I0), IC1.13 (I1)
LSPINB: CON1.A25, CON1.C25, IC1.9 (I0), IC1.10 (I1)
unnamed: QG1.3 (FO), R2.1, R3.1, R4.1, R5.1, R6.1
unnamed: LED2.A1 (A), R8.1
unnamed: IC2.3 (O), IC2.4 (I0), IC2.5 (I1)
unnamed: LED1.A1 (A), R7.1
unnamed: LED3.C1, R13.1
unnamed: LED4.C1, R13.2
unnamed: LED3.C2, R13.3
unnamed: LED4.C2, R13.4
unnamed: LED4.C3, R13.6
unnamed: LED4.C4, R13.8
unnamed: LED3.C4, R13.7
unnamed: LED3.C3, R13.5
unnamed: LED5.C1, R14.15
unnamed: LED6.C1, R14.16
unnamed: LED6.C2, R14.14
unnamed: LED5.C2, R14.13
unnamed: LED6.C3, R14.12
unnamed: LED5.C3, R14.11
unnamed: LED6.C4, R14.10
unnamed: LED5.C4, R14.9
unnamed: IC2.9 (I0), IC2.10 (I1), IC2.11 (O)
unnamed: IC2.6 (O), IC2.12 (I0), LED2.C1 (C)
NOTERROR: CON2.11 (NOTERROR), CON3.11 (NOTERROR), CON4.11 (NOTERROR), CON5.11 (NOTERROR), IC2.1 (I0), IC2.2 (I1), R10.1
OUT0: CON1.C8, CON5.12 (LINK0OUT), IC3.36 (I/O30)
OUT1: CON1.C16, CON5.4 (LINK1OUT), IC3.24 (I/O22)
OUT2: CON4.5 (LINK1IN), CON5.1 (LINK2OUT), IC3.22 (I/O20)
OUT3: CON1.A7, CON5.15 (LINK3OUT), IC3.37 (I/O31)
OUT4: CON1.C10, CON4.12 (LINK0OUT), IC3.34 (I/O28)
OUT5: CON4.4 (LINK1OUT), CON5.2 (LINK2IN), IC3.23 (I/O21)
OUT6: CON3.5 (LINK1IN), CON4.1 (LINK2OUT), IC3.21 (I/O19)
OUT7: CON1.A9, CON4.15 (LINK3OUT), IC3.35 (I/O29)
OUT8: CON1.C12, CON3.12 (LINK0OUT), IC3.32 (I/O26)
OUT9: CON3.4 (LINK1OUT), CON4.2 (LINK2IN), IC3.20 (I/O18)
OUT10: CON2.5 (LINK1IN), CON3.1 (LINK2OUT), IC3.18 (I/O16)
OUT11: CON1.A11, CON3.15 (LINK3OUT), IC3.33 (I/O27)
OUT12: CON1.C14, CON2.12 (LINK0OUT), IC3.30 (I/O24)
OUT13: CON2.4 (LINK1OUT), CON3.2 (LINK2IN), IC3.19 (I/O17)
OUT14: CON1.A15, CON2.1 (LINK2OUT), IC3.25 (I/O23)
OUT15: CON1.A13, CON2.15 (LINK3OUT), IC3.31 (I/O25)
RESET: CON2.10 (RESET), CON3.10 (RESET), CON4.10 (RESET), CON5.10 (RESET), IC1.6 (O)
RESIN: CON1.A23, CON1.C23, IC1.4 (I0), IC1.5 (I1), R1.1
TCK: CON1.C30, IC3.7 (TCK), R16.2
TDI: CON1.C29, IC3.4 (TDI), R15.1
TDO: CON1.A29, IC3.29 (TDO), R11.1
TEST: CON1.A26, CON1.C26, IC3.27 (CLK1)
TMS: CON1.A30, IC3.26 (TMS), R12.1
VCC: C1.+, C2.1, C3.1, C4.1, C5.1, C6.1, CON1.A1, CON1.A2, CON1.C1, CON1.C2, CON2.3 (VCC), CON3.3 (VCC), CON4.3 (VCC), CON5.3 (VCC), IC1.14 (VCC), IC2.14 (VCC), IC3.16 (VCC), IC3.38 (VCC), LED3.A1, LED3.A2, LED3.A3, LED3.A4, LED4.A1, LED4.A2, LED4.A3, LED4.A4, LED5.A1, LED5.A2, LED5.A3, LED5.A4, LED6.A1, LED6.A2, LED6.A3, LED6.A4, QG1.1 (OE), QG1.4 (VCC), R1.2, R7.2, R8.2, R9.2, R10.2, R11.2, R12.2, R15.2

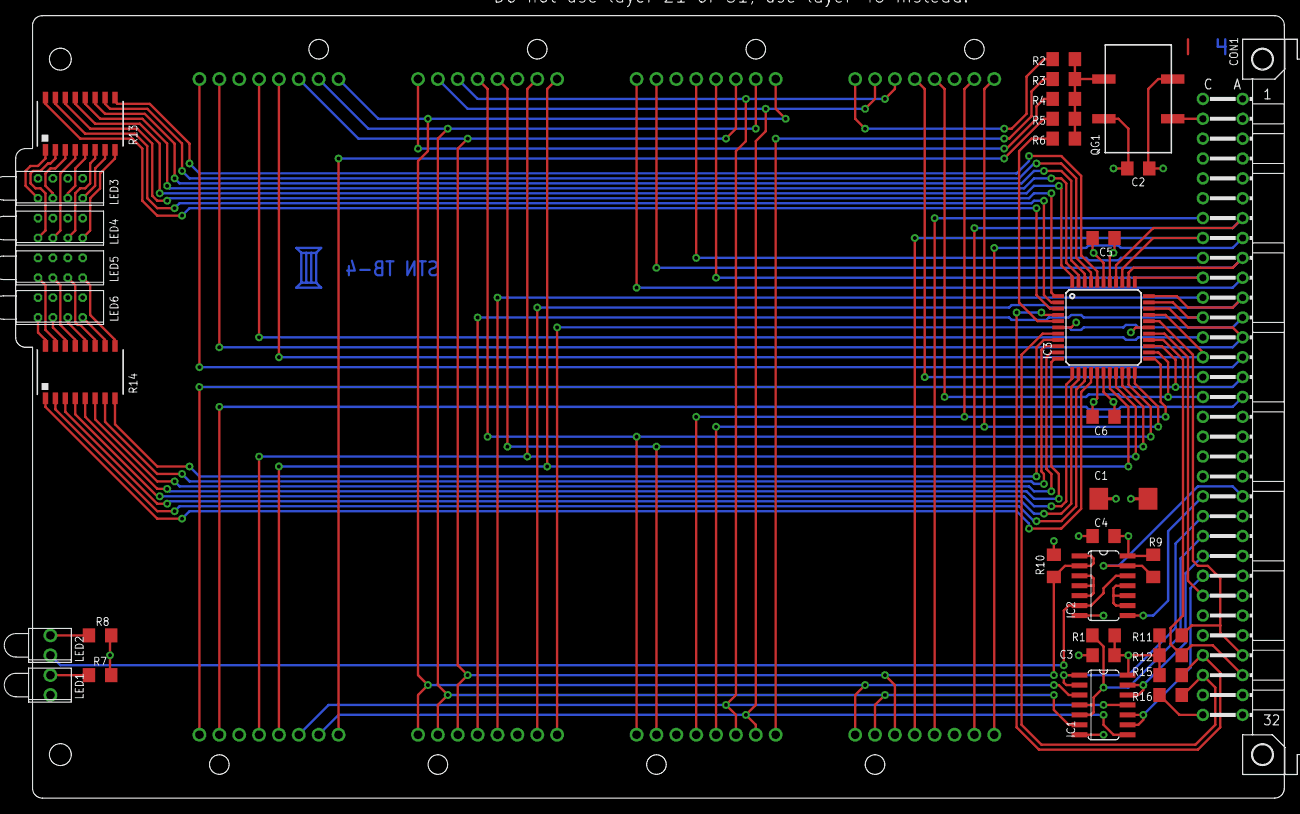
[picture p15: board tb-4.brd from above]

Board: 4 copper layers, 162.2 x 100.0 mm, 39 parts (1 on the bottom side), 87 nets.

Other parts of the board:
U$2: LOGO
U$3: LAYER14

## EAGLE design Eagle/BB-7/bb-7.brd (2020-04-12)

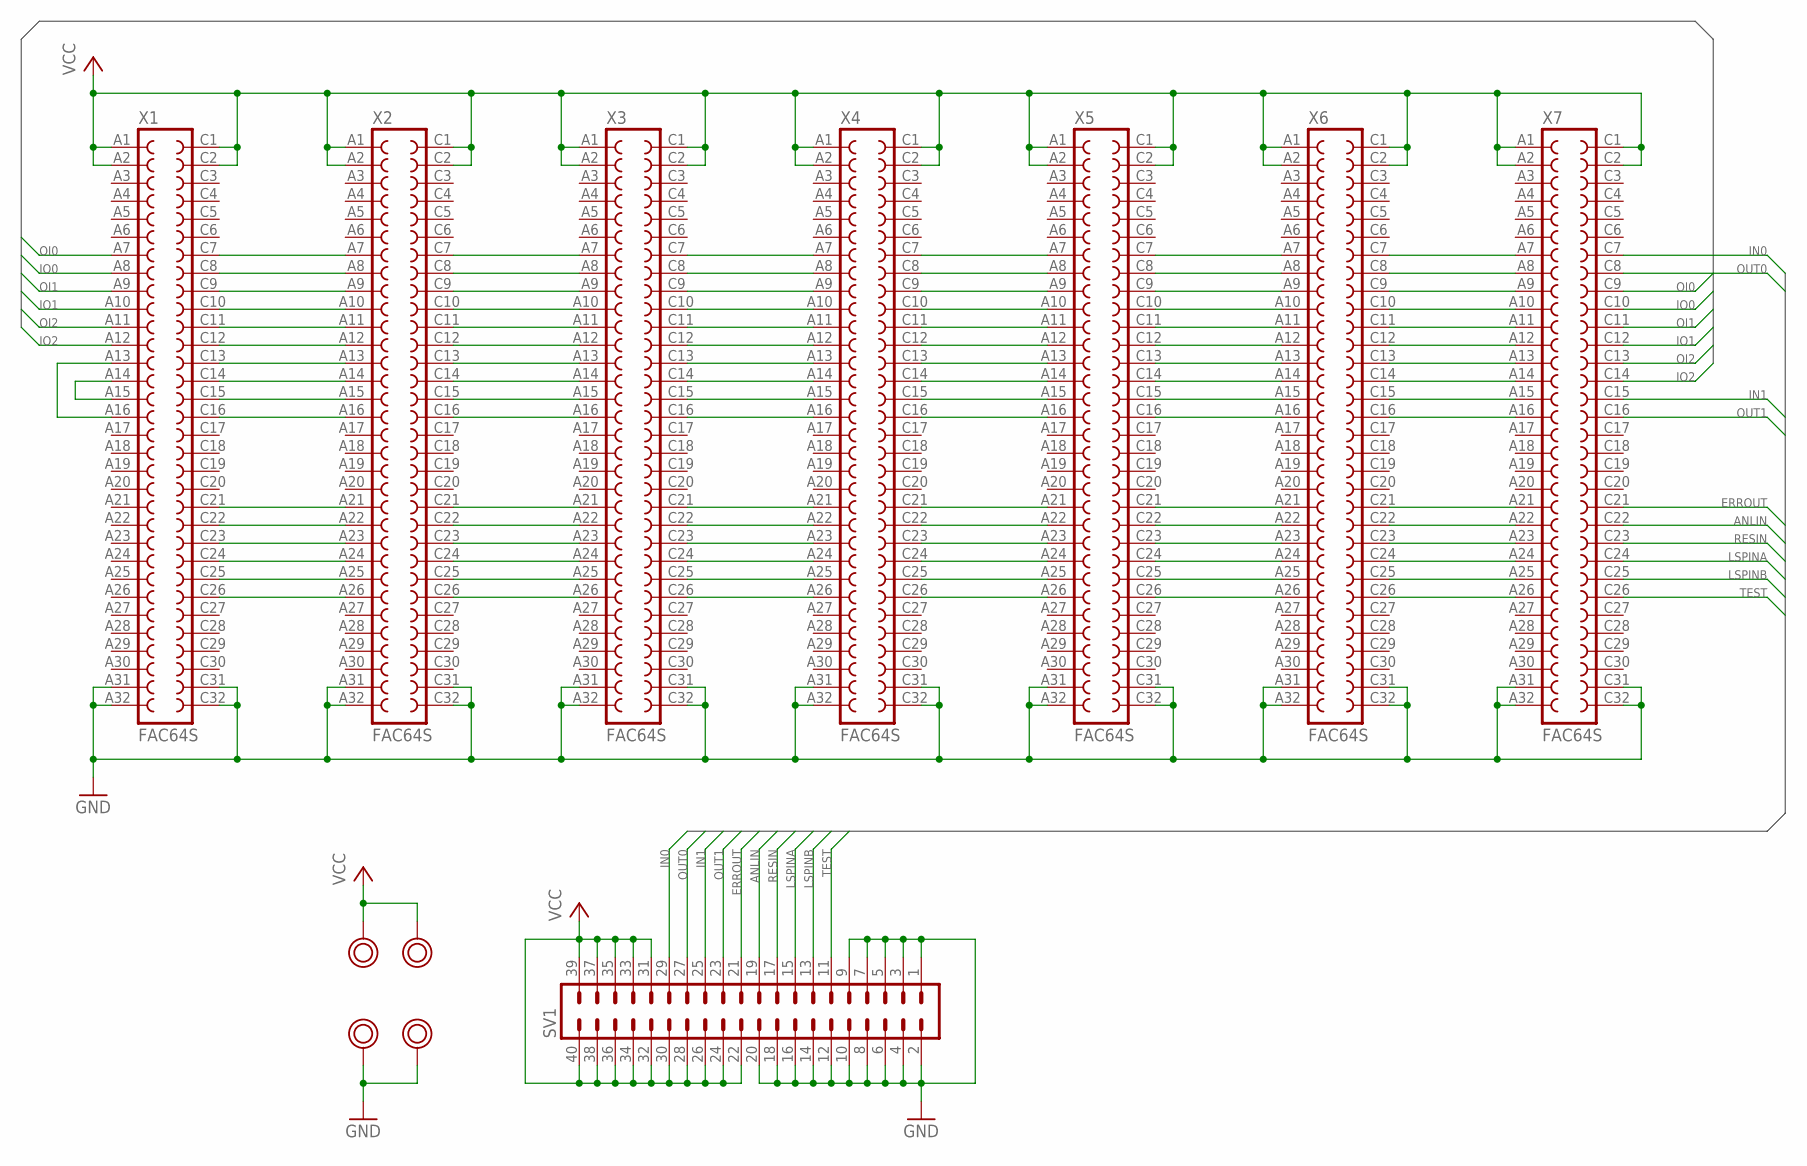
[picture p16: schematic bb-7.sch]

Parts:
SV1: MA20-2
U$3, U$4, U$5, U$6: POWERPAD
X1, X2, X3, X4, X5, X6, X7: FAC64S

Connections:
ANLIN: SV1.19, X7.C22
ERROUT: SV1.21, X7.C21
GND: SV1.1, SV1.2, SV1.3, SV1.4, SV1.5, SV1.6, SV1.7, SV1.8, SV1.9, SV1.10, SV1.12, SV1.14, SV1.16, SV1.18, SV1.20, U$3.P$1, U$4.P$1, X1.A31, X1.A32, X1.C31, X1.C32, X2.A31, X2.A32, X2.C31, X2.C32, X3.A31, X3.A32, X3.C31, X3.C32, X4.A31, X4.A32, X4.C31, X4.C32, X5.A31, X5.A32, X5.C31, X5.C32, X6.A31, X6.A32, X6.C31, X6.C32, X7.A31, X7.A32, X7.C31, X7.C32
IN0: SV1.29, X7.C7
IN1: SV1.25, X7.C15
IO0: X1.A8, X7.C10
IO1: X1.A10, X7.C12
IO2: X1.A12, X7.C14
LSPINA: SV1.15, X7.C24
LSPINB: SV1.13, X7.C25
unnamed: X1.A13, X1.A16
unnamed: X1.A14, X1.A15
unnamed: X4.C7, X5.A7
unnamed: X2.C7, X3.A7
unnamed: X2.C8, X3.A8
unnamed: X2.C9, X3.A9
unnamed: X1.C7, X2.A7
unnamed: X1.C8, X2.A8
unnamed: X1.C9, X2.A9
unnamed: X1.C10, X2.A10
unnamed: X1.C11, X2.A11
unnamed: X1.C12, X2.A12
unnamed: X1.C13, X2.A13
unnamed: X1.C14, X2.A14
unnamed: X1.C15, X2.A15
unnamed: X1.C16, X2.A16
unnamed: X2.C10, X3.A10
unnamed: X2.C11, X3.A11
unnamed: X2.C12, X3.A12
unnamed: X2.C13, X3.A13
unnamed: X1.C21, X2.A21
unnamed: X1.C22, X2.A22
unnamed: X1.C23, X2.A23
unnamed: X1.C24, X2.A24
unnamed: X1.C25, X2.A25
unnamed: X1.C26, X2.A26
unnamed: X2.C14, X3.A14
unnamed: X2.C15, X3.A15
unnamed: X2.C16, X3.A16
unnamed: X2.C21, X3.A21
unnamed: X2.C22, X3.A22
unnamed: X2.C23, X3.A23
unnamed: X2.C24, X3.A24
unnamed: X2.C25, X3.A25
unnamed: X2.C26, X3.A26
unnamed: X4.C8, X5.A8
unnamed: X4.C9, X5.A9
unnamed: X3.C7, X4.A7
unnamed: X3.C8, X4.A8
unnamed: X3.C9, X4.A9
unnamed: X3.C10, X4.A10
unnamed: X3.C11, X4.A11
unnamed: X3.C12, X4.A12
unnamed: X3.C13, X4.A13
unnamed: X3.C14, X4.A14
unnamed: X3.C15, X4.A15
unnamed: X3.C16, X4.A16
unnamed: X3.C21, X4.A21
unnamed: X3.C22, X4.A22
unnamed: X3.C23, X4.A23
unnamed: X3.C24, X4.A24
unnamed: X3.C25, X4.A25
unnamed: X3.C26, X4.A26
unnamed: X4.C10, X5.A10
unnamed: X4.C11, X5.A11
unnamed: X4.C12, X5.A12
unnamed: X4.C13, X5.A13
unnamed: X4.C14, X5.A14
unnamed: X4.C15, X5.A15
unnamed: X4.C16, X5.A16
unnamed: X4.C21, X5.A21
unnamed: X4.C22, X5.A22
unnamed: X4.C23, X5.A23
unnamed: X4.C24, X5.A24
unnamed: X4.C25, X5.A25
unnamed: X4.C26, X5.A26
unnamed: X5.C7, X6.A7
unnamed: X5.C8, X6.A8
unnamed: X5.C9, X6.A9
unnamed: X5.C10, X6.A10
unnamed: X5.C11, X6.A11
unnamed: X5.C12, X6.A12
unnamed: X5.C13, X6.A13
unnamed: X5.C14, X6.A14
unnamed: X5.C15, X6.A15
unnamed: X5.C16, X6.A16
unnamed: X5.C21, X6.A21
unnamed: X5.C22, X6.A22
unnamed: X5.C23, X6.A23
unnamed: X5.C24, X6.A24
unnamed: X5.C25, X6.A25
unnamed: X5.C26, X6.A26
unnamed: X6.C7, X7.A7
unnamed: X6.C8, X7.A8
unnamed: X6.C9, X7.A9
unnamed: X6.C10, X7.A10
unnamed: X6.C11, X7.A11
unnamed: X6.C12, X7.A12
unnamed: X6.C13, X7.A13
unnamed: X6.C14, X7.A14
unnamed: X6.C15, X7.A15
unnamed: X6.C16, X7.A16
unnamed: X6.C21, X7.A21
unnamed: X6.C22, X7.A22
unnamed: X6.C23, X7.A23
unnamed: X6.C24, X7.A24
unnamed: X6.C25, X7.A25
unnamed: X6.C26, X7.A26
OI0: X1.A7, X7.C9
OI1: X1.A9, X7.C11
OI2: X1.A11, X7.C13
OUT0: SV1.27, X7.C8
OUT1: SV1.23, X7.C16
RESIN: SV1.17, X7.C23
TEST: SV1.11, X7.C26
VCC: SV1.22, SV1.24, SV1.26, SV1.28, SV1.30, SV1.31, SV1.32, SV1.33, SV1.34, SV1.35, SV1.36, SV1.37, SV1.38, SV1.39, SV1.40, U$5.P$1, U$6.P$1, X1.A1, X1.A2, X1.C1, X1.C2, X2.A1, X2.A2, X2.C1, X2.C2, X3.A1, X3.A2, X3.C1, X3.C2, X4.A1, X4.A2, X4.C1, X4.C2, X5.A1, X5.A2, X5.C1, X5.C2, X6.A1, X6.A2, X6.C1, X6.C2, X7.A1, X7.A2, X7.C1, X7.C2

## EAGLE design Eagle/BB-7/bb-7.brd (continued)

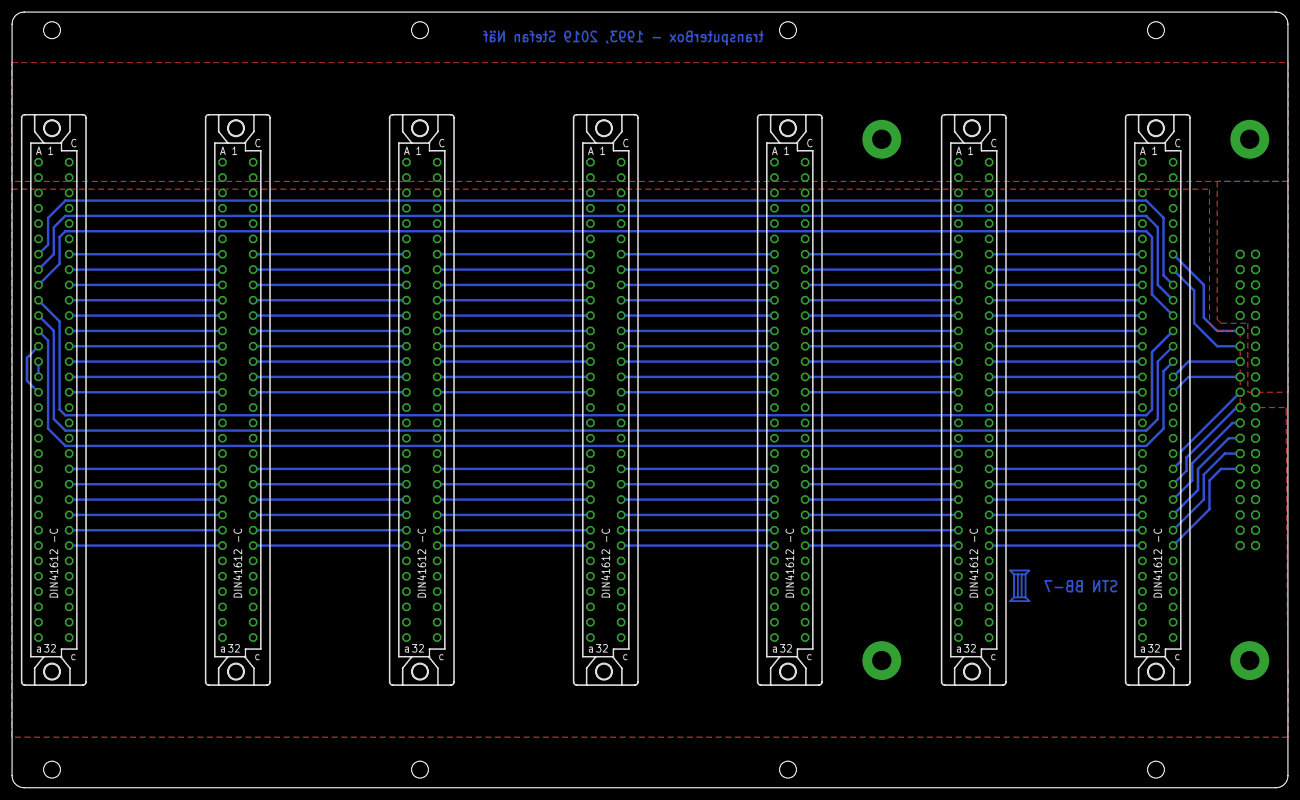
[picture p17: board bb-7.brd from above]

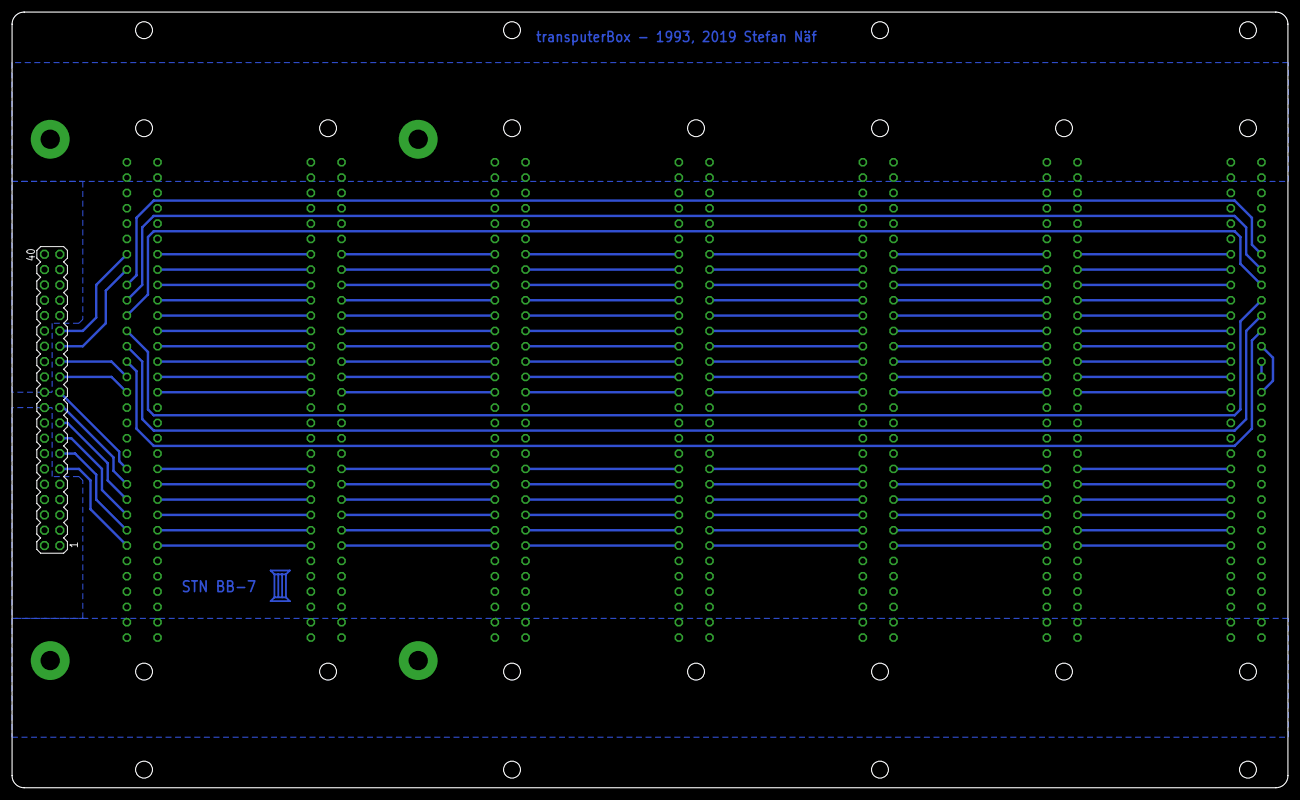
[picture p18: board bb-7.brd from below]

Board: 2 copper layers, 211.4 x 128.5 mm, 13 parts (2 on the bottom side), 116 nets.

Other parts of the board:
U$1: LOGO

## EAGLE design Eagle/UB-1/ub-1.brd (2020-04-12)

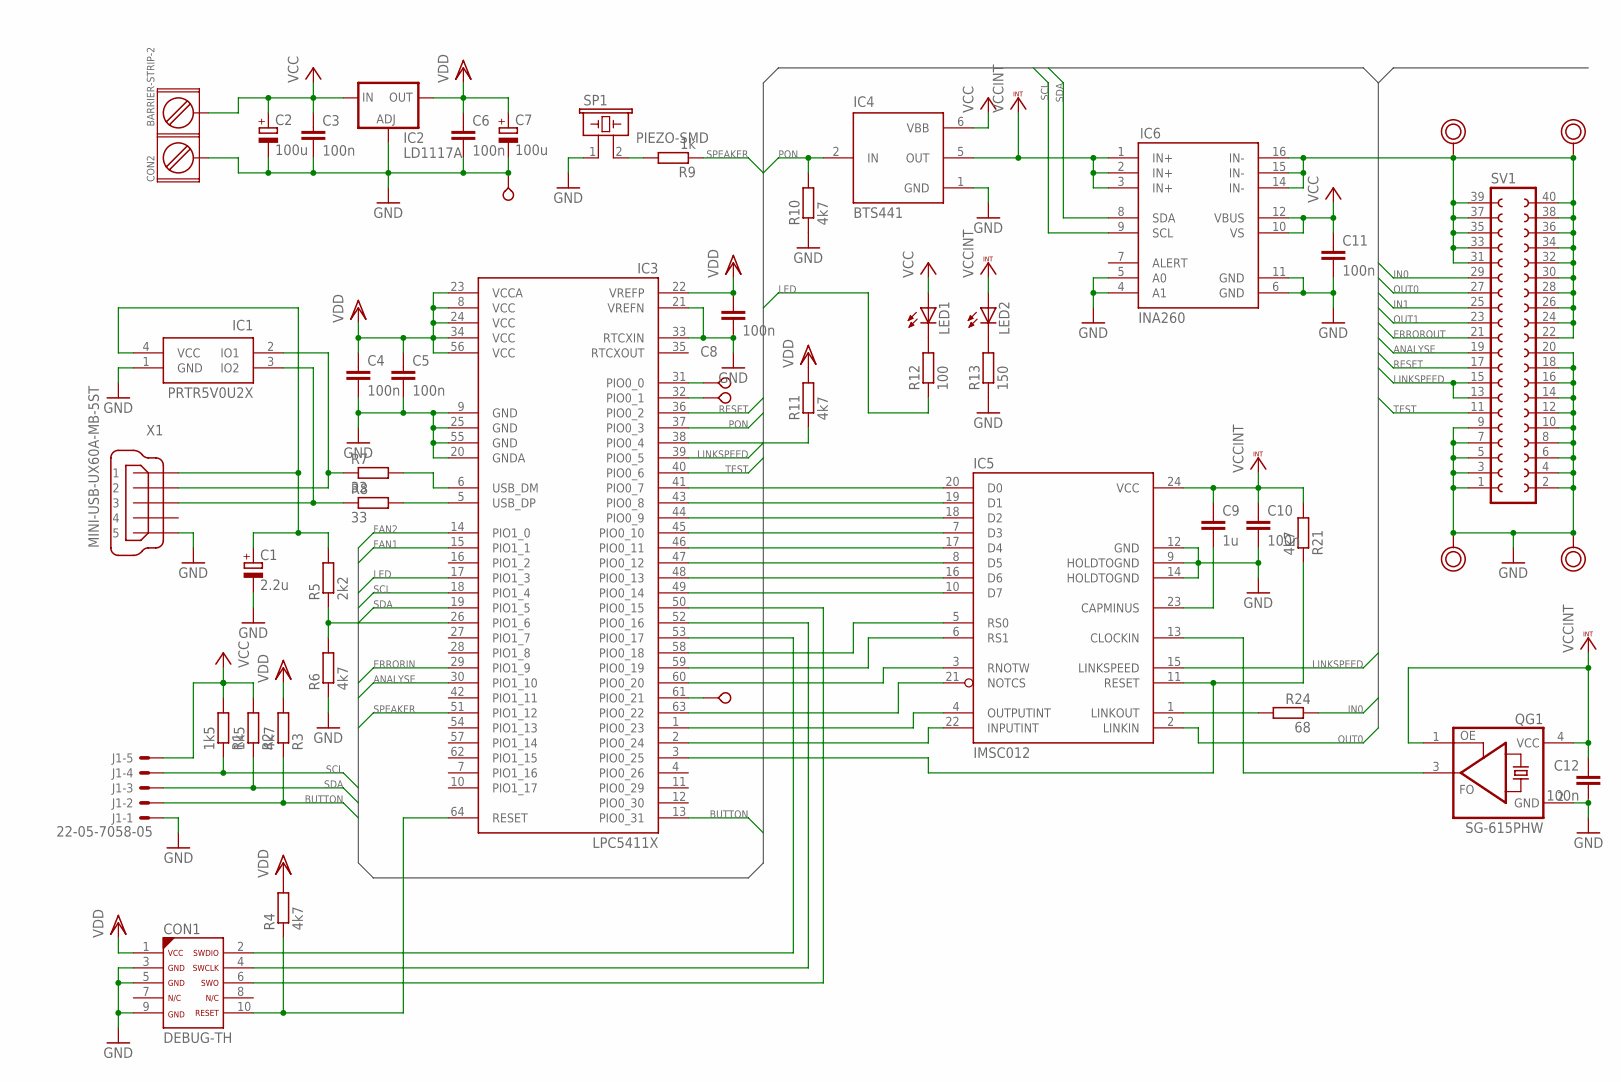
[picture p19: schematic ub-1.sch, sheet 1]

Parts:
C1: 2.2u; SMC_B; DIGIKEY 478-3880-1-ND
C2, C7: 100u; SMC_B; DIGIKEY 478-5801-1-ND
C3, C4, C5, C6, C8, C10, C11, C12: 100n; C1206; DIGIKEY 478-10855-1-ND
C9: 1u; C1206; DIGIKEY 478-1567-1-ND
CON1: DEBUG-TH; DIGIKEY 1175-1627-ND
CON2: BARRIER-STRIP-2; DIGIKEY WM13929-ND
IC1: PRTR5V0U2X; SOT143; DIGIKEY 1727-3884-1-ND
IC2: LD1117A; SOT223; DIGIKEY 497-1228-1-ND
IC3: LPC5411X; LQPF64; DIGIKEY 568-13034-ND
IC4: BTS441; TO263-4; DIGIKEY BTS441TGATMA1CT-ND
IC5: IMSC012; DIL24-3
IC6: INA260; TSSOP-16; DIGIKEY 296-47777-1-ND
J1: 22-05-7058-05; 7395-05; DIGIKEY WM2787-ND
LED1, LED2: LEDSMT1206; 1206; DIGIKEY 160-1404-1-ND
QG1: SG-615PHW; SG-615
R1, R2: 1k5; R1206; DIGIKEY CR1206-FX-1501ELFCT-ND
R3, R4, R6, R10, R11, R21: 4k7; R1206; DIGIKEY CR1206-FX-4701ELFCT-ND
R5: 2k2; R1206; DIGIKEY CR1206-FX-2201ELFCT-ND
R7, R8: 33; R1206; DIGIKEY CRS1206-FX-33R0ELFCT-ND
R9: 1k; R1206; DIGIKEY CR1206-FX-1001ELFCT-ND
R12: 100; R1206; DIGIKEY CR1206-FX-1000ELFCT-ND
R13: 150; R1206; DIGIKEY CR1206-FX-1500ELFCT-ND
R24: 68; R1206; DIGIKEY CR1206-FX-68R0ELFCT-ND
SCREW1, SCREW2, SCREW3, SCREW4: POWERPAD
SP1: PIEZO-SMD; DIGIKEY 490-9647-1-ND
SV1: FE20-2
TP1, TP2, TP3, TP4: TESTPOINT; VERO_TP
X1: MINI-USB-UX60A-MB-5ST; UX60A-MB-5ST; DIGIKEY H2961CT-ND

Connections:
ANALYSE: IC3.30 (PIO1_10), SV1.19; also elsewhere on the board
BUTTON: IC3.13 (PIO0_31), J1.2, R3.1
ERRORIN: IC3.29 (PIO1_9); also elsewhere on the board
ERROROUT: SV1.21; also elsewhere on the board
FAN1: IC3.15 (PIO1_1); also elsewhere on the board
FAN2: IC3.14 (PIO1_0); also elsewhere on the board
GND: C1.-, C2.-, C3.2, C4.2, C5.2, C6.2, C7.-, C8.2, C10.2, C11.2, C12.2, CON1.3, CON1.5, CON1.9, CON2.1, IC1.1 (GND), IC2.1 (ADJ), IC3.9 (GND), IC3.20 (GNDA), IC3.21 (VREFN), IC3.25 (GND), IC3.33 (RTCXIN), IC3.55 (GND), IC4.1 (GND), IC5.9 (HOLDTOGND), IC5.12 (GND), IC5.14 (HOLDTOGND), IC6.4 (A1), IC6.5 (A0), IC6.6 (GND), IC6.11 (GND), J1.1, QG1.2 (GND), R6.1, R10.1, R13.1, SCREW2.P$1, SCREW4.P$1, SP1.1, SV1.1, SV1.2, SV1.3, SV1.4, SV1.5, SV1.6, SV1.7, SV1.8, SV1.9, SV1.10, SV1.12, SV1.14, SV1.16, SV1.18, SV1.20, TP3.P$1, X1.5; also elsewhere on the board
IN0: R24.1, SV1.29
IN1: SV1.25; also elsewhere on the board
LED: IC3.17 (PIO1_3), R12.1
LINKSPEED: IC3.39 (PIO0_5), IC5.15 (LINKSPEED), SV1.13, SV1.15
unnamed: CON1.2, IC3.53 (PIO0_17)
unnamed: IC3.31 (PIO0_0), TP1.P$1
unnamed: CON1.4, IC3.52 (PIO0_16)
unnamed: CON1.10, IC3.64 (RESET), R4.1
unnamed: IC3.26 (PIO1_6), R5.1, R6.2
unnamed: IC3.5 (USB_DP), R8.2
unnamed: IC3.6 (USB_DM), R7.2
unnamed: IC6.14 (IN-), IC6.15 (IN-), IC6.16 (IN-), SCREW1.P$1, SCREW3.P$1, SV1.22, SV1.24, SV1.26, SV1.28, SV1.30, SV1.31, SV1.32, SV1.33, SV1.34, SV1.35, SV1.36, SV1.37, SV1.38, SV1.39, SV1.40
unnamed: IC3.41 (PIO0_7), IC5.20 (D0)
unnamed: IC3.32 (PIO0_1), TP2.P$1
unnamed: IC3.61 (PIO0_21), TP4.P$1
unnamed: IC5.1 (LINKOUT), R24.2
unnamed: IC3.43 (PIO0_8), IC5.19 (D1)
unnamed: IC3.44 (PIO0_9), IC5.18 (D2)
unnamed: IC3.45 (PIO0_10), IC5.7 (D3)
unnamed: IC3.46 (PIO0_11), IC5.17 (D4)
unnamed: IC3.47 (PIO0_12), IC5.8 (D5)
unnamed: IC3.48 (PIO0_13), IC5.16 (D6)
unnamed: IC3.49 (PIO0_14), IC5.10 (D7)
unnamed: IC3.60 (PIO0_20), IC5.3 (RNOTW)
unnamed: IC3.59 (PIO0_19), IC5.6 (RS1)
unnamed: IC3.58 (PIO0_18), IC5.5 (RS0)
unnamed: IC3.1 (PIO0_23), IC5.4 (OUTPUTINT)
unnamed: IC3.2 (PIO0_24), IC5.22 (INPUTINT)
unnamed: IC3.63 (PIO0_22), IC5.21 (NOTCS)
unnamed: IC5.13 (CLOCKIN), QG1.3 (FO)
unnamed: C9.2, IC5.23 (CAPMINUS)
unnamed: IC1.2 (IO1), R7.1, X1.2
unnamed: IC1.3 (IO2), R8.1, X1.3
unnamed: LED2.C, R13.2
unnamed: R9.2, SP1.2
unnamed: LED1.C, R12.2
unnamed: CON1.6, IC3.50 (PIO0_15)
unnamed: IC3.38 (PIO0_4), R11.1
unnamed: IC3.3 (PIO0_25), IC5.11 (RESET), R21.1
OUT0: IC5.2 (LINKIN), SV1.27
OUT1: SV1.23; also elsewhere on the board
PON: IC3.37 (PIO0_3), IC4.2 (IN), R10.2; also elsewhere on the board
RESET: IC3.36 (PIO0_2), SV1.17; also elsewhere on the board
SCL: IC3.18 (PIO1_4), IC6.9 (SCL), J1.4, R1.1
SDA: IC3.19 (PIO1_5), IC6.8 (SDA), J1.3, R2.1
SPEAKER: IC3.51 (PIO1_12), R9.1
TEST: IC3.40 (PIO0_6), SV1.11
VCC: C2.+, C3.1, C11.1, CON2.2, IC2.3 (IN), IC4.6 (VBB), IC6.10 (VS), IC6.12 (VBUS), J1.5, LED1.A, R1.2, R2.2; also elsewhere on the board
VCCINT: C9.1, C10.1, C12.1, IC4.5 (OUT), IC5.24 (VCC), IC6.1 (IN+), IC6.2 (IN+), IC6.3 (IN+), LED2.A, QG1.1 (OE), QG1.4 (VCC), R21.2; also elsewhere on the board
VDD: C4.1, C5.1, C6.1, C7.+, C8.1, CON1.1, IC2.2 (OUT), IC3.8 (VCC), IC3.22 (VREFP), IC3.23 (VCCA), IC3.24 (VCC), IC3.34 (VCC), IC3.56 (VCC), R3.2, R4.2, R11.2
VUSB: C1.+, IC1.4 (VCC), R5.2, X1.1

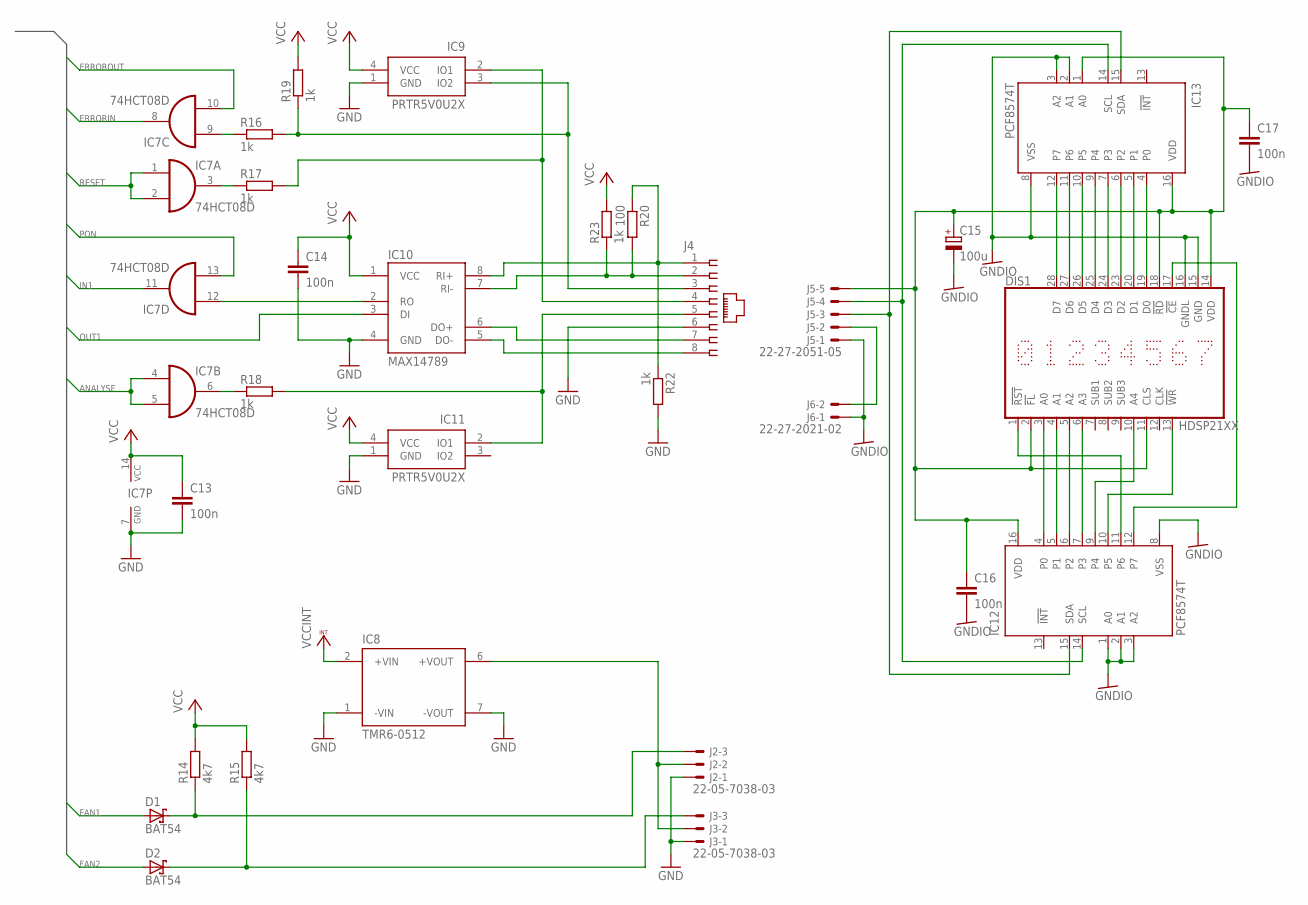
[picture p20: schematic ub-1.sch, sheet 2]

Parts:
C13, C14, C16, C17: 100n; C1206; DIGIKEY 478-10855-1-ND
C15: 100u; SMC_B; DIGIKEY 478-5801-1-ND
D1, D2: BAT54; SOT23; DIGIKEY BAT54FSCT-ND
DIS1: HDSP21XX; DIGIKEY 516-1161-5-ND
IC7: 74HCT08D; SO14; DIGIKEY 296-14862-1-ND
IC8: TMR6-0512; DIGIKEY 1951-2391-ND
IC9, IC11: PRTR5V0U2X; SOT143; DIGIKEY 1727-3884-1-ND
IC10: MAX14789; SO8; DIGIKEY MAX14789EGSA+-ND
IC12, IC13: PCF8574T; SO16W; DIGIKEY 568-1077-1-ND
J2, J3: 22-05-7038-03; 7395-03; DIGIKEY WM2785-ND
J4: 555164-1; DIGIKEY A31442-ND
J5: 22-27-2051-05; 6410-05; DIGIKEY WM4114-ND
J6: 22-27-2021-02; 6410-02; DIGIKEY WM4111-ND
R14, R15: 4k7; R1206; DIGIKEY CR1206-FX-4701ELFCT-ND
R16, R17, R18, R19, R22, R23: 1k; R1206; DIGIKEY CR1206-FX-1001ELFCT-ND
R20: 100; R1206; DIGIKEY CR1206-FX-1000ELFCT-ND

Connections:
ANALYSE: IC7.4 (I0), IC7.5 (I1); also elsewhere on the board
ERRORIN: IC7.8 (O); also elsewhere on the board
ERROROUT: IC7.10 (I1); also elsewhere on the board
FAN1: D1.1 (A); also elsewhere on the board
FAN2: D2.1 (A); also elsewhere on the board
GND: C13.2, C14.2, IC7.7 (GND), IC8.1 (-VIN), IC8.7 (-VOUT), IC9.1 (GND), IC10.4 (GND), IC11.1 (GND), J2.1, J3.1, J4.6, R22.2; also elsewhere on the board
GNDIO: C15.-, C16.2, C17.2, DIS1.15 (GND), DIS1.16 (GNDL), IC12.1 (A0), IC12.2 (A1), IC12.3 (A2), IC12.8 (VSS), IC13.2 (A1), IC13.3 (A2), IC13.8 (VSS), J5.1, J6.1
IN1: IC7.11 (O); also elsewhere on the board
unnamed: DIS1.3 (A0), IC12.4 (P0)
unnamed: DIS1.19 (D0), IC13.4 (P0)
unnamed: DIS1.20 (D1), IC13.5 (P1)
unnamed: DIS1.23 (D2), IC13.6 (P2)
unnamed: DIS1.24 (D3), IC13.7 (P3)
unnamed: DIS1.25 (D4), IC13.9 (P4)
unnamed: DIS1.26 (D5), IC13.10 (P5)
unnamed: DIS1.27 (D6), IC13.11 (P6)
unnamed: DIS1.28 (D7), IC13.12 (P7)
unnamed: DIS1.4 (A1), IC12.5 (P1)
unnamed: DIS1.5 (A2), IC12.6 (P2)
unnamed: DIS1.6 (A3), IC12.7 (P3)
unnamed: DIS1.10 (A4), IC12.9 (P4)
unnamed: J5.2, J6.2
unnamed: C15.+, C16.1, C17.1, DIS1.2 (!FL), DIS1.11 (CLS), DIS1.14 (VDD), DIS1.18 (!RD), IC12.16 (VDD), IC13.1 (A0), IC13.16 (VDD), J5.5
unnamed: DIS1.1 (!RST), IC12.11 (P6)
unnamed: DIS1.13 (!WR), IC12.10 (P5)
unnamed: IC12.14 (SCL), IC13.14 (SCL), J5.4
unnamed: DIS1.17 (!CE), IC12.12 (P7)
unnamed: IC12.15 (SDA), IC13.15 (SDA), J5.3
unnamed: IC10.8 (RI+), J4.1, R20.1, R22.1
unnamed: IC10.7 (RI-), J4.2, R20.2, R23.1
unnamed: IC10.5 (DO-), J4.8
unnamed: IC10.6 (DO+), J4.7
unnamed: IC7.6 (O), R18.1
unnamed: IC7.3 (O), R17.1
unnamed: IC7.9 (I0), R16.1
unnamed: IC9.3 (IO2), J4.3, R16.2, R19.1
unnamed: IC9.2 (IO1), J4.4, R17.2
unnamed: IC11.2 (IO1), J4.5, R18.2
unnamed: IC7.12 (I0), IC10.2 (RO)
unnamed: D2.3 (C), J3.3, R15.1
unnamed: D1.3 (C), J2.3, R14.1
unnamed: IC8.6 (+VOUT), J2.2, J3.2
OUT1: IC10.3 (DI); also elsewhere on the board
PON: IC7.13 (I1); also elsewhere on the board
RESET: IC7.1 (I0), IC7.2 (I1); also elsewhere on the board
VCC: C13.1, C14.1, IC7.14 (VCC), IC9.4 (VCC), IC10.1 (VCC), IC11.4 (VCC), R14.2, R15.2, R19.2, R23.2; also elsewhere on the board
VCCINT: IC8.2 (+VIN); also elsewhere on the board

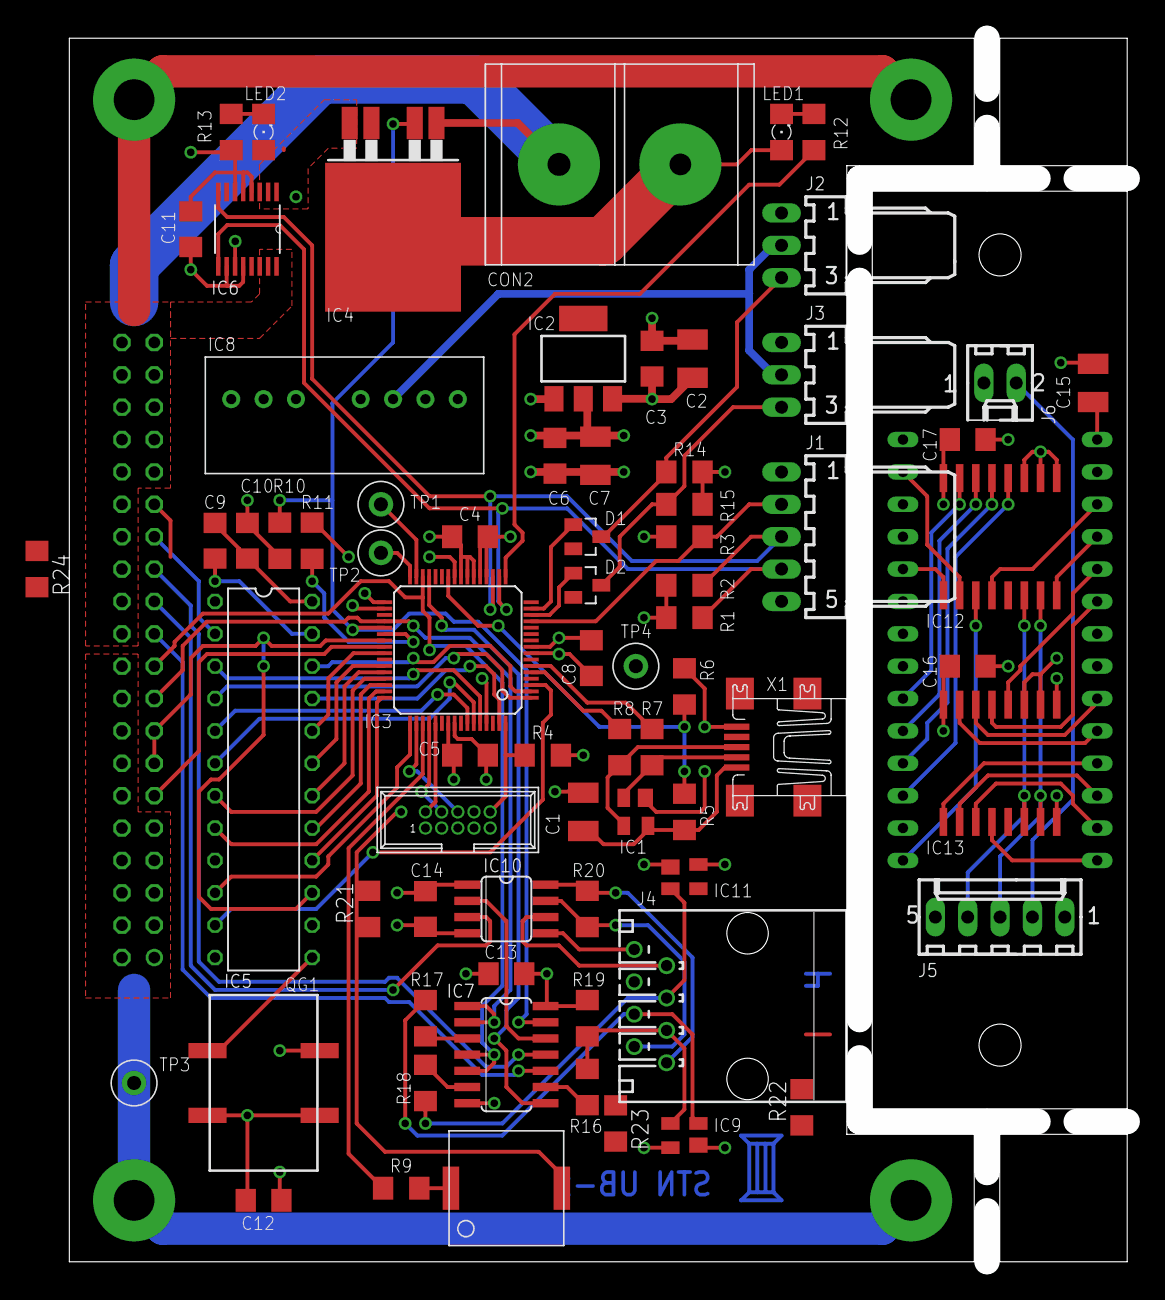
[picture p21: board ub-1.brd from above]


Board: 4 copper layers, 83.0 x 96.0 mm, 81 parts (3 on the bottom side), 93 nets.

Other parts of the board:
U$5: LAYER14
U$6: LOGO

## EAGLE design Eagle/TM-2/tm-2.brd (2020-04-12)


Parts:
C1, C2, C3, C4: 100n; C1206
C5: 1u; C1206
D1, D2: BAV70; SOT23
IC1: IMST800; PGA84
IC2, IC3: 74HCT373DW; SO20W
IC4, IC5, IC6, IC7: CY62256N; SOP28N
PCB1: TRAM-1-PCB
R1, R2, R3, R4, R5, R6, R7, R8: 10k; R1206
R9, R10, R11, R12: 56; R1206
SW1: DIP-SW-CVS-03
T1: BC847; SOT23

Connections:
A2: IC2.2 (1Q), IC4.10 (A0), IC5.10 (A0), IC6.10 (A0), IC7.10 (A0)
A3: IC2.12 (5Q), IC4.9 (A1), IC5.9 (A1), IC6.9 (A1), IC7.9 (A1)
A4: IC3.16 (7Q), IC4.8 (A2), IC5.8 (A2), IC6.8 (A2), IC7.8 (A2)
A5: IC2.6 (3Q), IC4.7 (A3), IC5.7 (A3), IC6.7 (A3), IC7.7 (A3)
A6: IC2.9 (4Q), IC4.6 (A4), IC5.6 (A4), IC6.6 (A4), IC7.6 (A4)
A7: IC2.19 (8Q), IC4.5 (A5), IC5.5 (A5), IC6.5 (A5), IC7.5 (A5)
A8: IC2.16 (7Q), IC4.4 (A6), IC5.4 (A6), IC6.4 (A6), IC7.4 (A6)
A9: IC2.15 (6Q), IC4.3 (A7), IC5.3 (A7), IC6.3 (A7), IC7.3 (A7)
A10: IC2.5 (2Q), IC4.25 (A8), IC5.25 (A8), IC6.25 (A8), IC7.25 (A8)
A11: IC3.15 (6Q), IC4.24 (A9), IC5.24 (A9), IC6.24 (A9), IC7.24 (A9)
A12: IC3.2 (1Q), IC4.21 (A10), IC5.21 (A10), IC6.21 (A10), IC7.21 (A10)
A13: IC3.5 (2Q), IC4.23 (A11), IC5.23 (A11), IC6.23 (A11), IC7.23 (A11)
A14: IC3.12 (5Q), IC4.2 (A12), IC5.2 (A12), IC6.2 (A12), IC7.2 (A12)
A15: IC3.6 (3Q), IC4.26 (A13), IC5.26 (A13), IC6.26 (A13), IC7.26 (A13)
A16: IC3.9 (4Q), IC4.1 (A14), IC5.1 (A14), IC6.1 (A14), IC7.1 (A14)
AD0: IC1.G8 (NOTMEMWRD0), IC4.17 (I/O5)
AD1: IC1.H10 (NOTMEMRFD1), IC4.13 (I/O2)
AD2: IC1.J10 (MEMAD2), IC2.3 (1D), IC4.12 (I/O1)
AD3: IC1.H9 (MEMAD3), IC2.13 (5D), IC4.18 (I/O6)
AD4: IC1.H8 (MEMAD4), IC3.17 (7D), IC4.15 (I/O3)
AD5: IC1.J9 (MEMAD5), IC2.7 (3D), IC4.19 (I/O7)
AD6: IC1.J8 (MEMAD6), IC2.8 (4D), IC4.16 (I/O4)
AD7: IC1.K10 (MEMAD7), IC2.18 (8D), IC4.11 (I/O0)
AD8: IC1.C8 (MEMCONFIG), IC1.H7 (MEMAD8), IC2.17 (7D), IC5.11 (I/O0)
AD9: IC1.K9 (MEMAD9), IC2.14 (6D), IC5.13 (I/O2)
AD10: IC1.K8 (MEMAD10), IC2.4 (2D), IC5.12 (I/O1)
AD11: IC1.K7 (MEMAD11), IC3.14 (6D), IC5.15 (I/O3)
AD12: IC1.H6 (MEMAD12), IC3.3 (1D), IC5.16 (I/O4)
AD13: IC1.J6 (MEMAD13), IC3.4 (2D), IC5.17 (I/O5)
AD14: IC1.K6 (MEMAD14), IC3.13 (5D), IC5.18 (I/O6)
AD15: IC1.K5 (MEMAD15), IC3.7 (3D), IC5.19 (I/O7)
AD16: IC1.H5 (MEMAD16), IC3.8 (4D), IC6.12 (I/O1)
AD17: IC1.J5 (MEMAD17), IC6.11 (I/O0)
AD18: IC1.K4 (MEMAD18), IC6.13 (I/O2)
AD19: IC1.J4 (MEMAD19), IC6.19 (I/O7)
AD20: IC1.K3 (MEMAD20), IC6.16 (I/O4)
AD21: IC1.K2 (MEMAD21), IC6.15 (I/O3)
AD22: IC1.J3 (MEMAD22), IC6.17 (I/O5)
AD23: IC1.H3 (MEMAD23), IC6.18 (I/O6)
AD24: IC1.J2 (MEMAD24), IC7.11 (I/O0)
AD25: IC1.H2 (MEMAD25), IC7.12 (I/O1)
AD26: IC1.K1 (MEMAD26), IC7.15 (I/O3)
AD27: IC1.G3 (MEMAD27), IC7.13 (I/O2)
AD28: IC1.J1 (MEMAD28), IC7.16 (I/O4)
AD29: IC1.H1 (MEMAD29), IC7.17 (I/O5)
AD30: IC1.G1 (MEMAD30), IC7.18 (I/O6)
AD31: IC1.F3 (MEMAD31), IC7.19 (I/O7)
E: IC1.E9 (NOTMEMS0), IC4.20 (!CS), IC5.20 (!CS), IC6.20 (!CS), IC7.20 (!CS)
GND: C1.2, C2.2, C3.2, C4.2, IC1.A9 (GND), IC1.A10 (MEMWAIT), IC1.B8 (EVENTREQ), IC1.B9 (MEMREQ), IC1.C1 (GND), IC1.D3 (ERRIN), IC1.E1 (DISABLEINTRAM), IC1.E2 (BOOTFROMROM), IC1.G2 (GND), IC1.G9 (GND), IC1.J7 (GND), IC2.1 (OC), IC2.10 (GND), IC3.1 (OC), IC3.10 (GND), IC3.18 (8D), IC4.14 (VSS), IC5.14 (VSS), IC6.14 (VSS), IC7.14 (VSS), PCB1.14 (GND), R1.1, R2.1, R5.1, R7.1, SW1.1, SW1.2, SW1.3, T1.2 (E)
unnamed: IC1.G10 (NOTMEMS1), IC2.11 (ENC), IC3.11 (ENC)
unnamed: IC1.B5 (LINKOUT0), R9.1
unnamed: C5.1, IC1.C4 (CAP+)
unnamed: C5.2, IC1.C3 (CAP-)
unnamed: IC1.A6 (LINKOUT1), R10.1
unnamed: IC1.B6 (LINKOUT2), R11.1
unnamed: IC1.B7 (LINKOUT3), R12.1
unnamed: PCB1.4 (LINK1OUT), R10.2
unnamed: PCB1.12 (LINK0OUT), R9.2
unnamed: D2.2 (A2), IC1.A7 (LINKIN2), PCB1.2 (LINK2IN), R7.2
unnamed: D2.1 (A1), IC1.C6 (LINKIN1), PCB1.5 (LINK1IN), R2.2
unnamed: D1.1 (A1), IC1.A5 (LINKIN0), PCB1.13 (LINK0IN), R1.2
unnamed: PCB1.1 (LINK2OUT), R11.2
unnamed: D1.2 (A2), IC1.C7 (LINKIN3), PCB1.16 (LINK3IN), R5.2
unnamed: PCB1.15 (LINK3OUT), R12.2
unnamed: IC1.D1 (ERROUT), R6.1
unnamed: IC1.E3 (RESET), PCB1.10 (RESET)
unnamed: IC1.F2 (ANALYSE), PCB1.9 (ANALYSE)
unnamed: IC1.B2 (CLKIN), PCB1.8 (CLOCKIN)
unnamed: IC1.A4 (LINKSPEED123), PCB1.6 (LINKSPEEDA)
unnamed: IC1.B4 (LINKSPEED0), PCB1.7 (LINKSPEEDB)
unnamed: IC1.B1 (PROCSPEED0), R3.2, SW1.6
unnamed: PCB1.11 (NOTERROR), T1.3 (C)
unnamed: R6.2, T1.1 (B)
unnamed: IC1.F1 (PROCSPEED1), R4.2, SW1.5
unnamed: IC1.D2 (PROCSPEED2), R8.2, SW1.4
RD: IC1.E8 (NOTMEMRD), IC4.22 (!OE), IC5.22 (!OE), IC6.22 (!OE), IC7.22 (!OE)
VCC: C1.1, C2.1, C3.1, C4.1, D1.3 (C), D2.3 (C), IC1.A2 (LINKSPECIAL), IC1.C2 (VCC), IC1.C5 (VCC), IC1.E10 (VCC), IC1.H4 (VCC), IC2.20 (VCC), IC3.20 (VCC), IC4.28 (VCC), IC5.28 (VCC), IC6.28 (VCC), IC7.28 (VCC), PCB1.3 (VCC), R3.1, R4.1, R8.1
WR0: IC1.D10 (NOTMEMWRB0), IC4.27 (!WE)
WR1: IC1.C10 (NOTMEMWRB1), IC5.27 (!WE)
WR2: IC1.D9 (NOTMEMWRB2), IC6.27 (!WE)
WR3: IC1.B10 (NOTMEMWRB3), IC7.27 (!WE)



Board: 6 copper layers, 93.0 x 26.7 mm, 30 parts (15 on the bottom side), 81 nets.

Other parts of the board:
U$2: LOGO

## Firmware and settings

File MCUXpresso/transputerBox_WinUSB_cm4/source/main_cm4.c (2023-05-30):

/*
 * @brief Vitual communication port example
 *
 * @note
 * Copyright  2013, NXP
 * All rights reserved.
 *
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
 * @par
 * Permission to use, copy, modify, and distribute this software and its
 * documentation is hereby granted, under NXP Semiconductors' and its
 * licensor's relevant copyrights in the software, without fee, provided that it
 * is used in conjunction with NXP Semiconductors microcontrollers.  This
 * copyright, permission, and disclaimer notice must appear in all copies of
 * this code.
 */

#include "board.h"
#include <stdio.h>
#include <string.h>
#include "mcmgr.h"
#include "pin_mux.h"
#include "peripherals.h"
#include "libusbdev.h"
#include "power.h"
#include "button.h"
#include "display.h"
#include "transputer.h"
#include "cooling.h"
#include "beep.h"

/*******************************************************************************
 * Definitions
 ******************************************************************************/

#define CHECK_TIMER(timer) {if(timer) timer--;}

/*******************************************************************************
 * Prototypes
 ******************************************************************************/

/*******************************************************************************
 * Variables
 ******************************************************************************/

/*******************************************************************************
 * Code
 ******************************************************************************/

void MRT_1_IRQHANDLER(void)
{
	// 100ms timer
	if (MRT_GetStatusFlags(MRT_1_PERIPHERAL, MRT_1_CHANNEL_0) & kMRT_TimerInterruptFlag)
	{
		MRT_ClearStatusFlags(MRT_1_PERIPHERAL, MRT_1_CHANNEL_0, kMRT_TimerInterruptFlag);
		beep_timer();
		cooling_timer();
	}

	// 10ms timer
	if (MRT_GetStatusFlags(MRT_1_PERIPHERAL, MRT_1_CHANNEL_1) & kMRT_TimerInterruptFlag)
	{
		MRT_ClearStatusFlags(MRT_1_PERIPHERAL, MRT_1_CHANNEL_1, kMRT_TimerInterruptFlag);
		CHECK_TIMER(power.timer_10ms);
		CHECK_TIMER(button.timer_10ms);
		CHECK_TIMER(transputer.upload_led_10ms);
		CHECK_TIMER(transputer.download_led_10ms);
		CHECK_TIMER(transputer.reset_led_10ms);
		CHECK_TIMER(transputer.analyse_led_10ms);
	}
}

void SystemInitHook(void)
{
    /* Initialize MCMGR - low level multicore management library. Call this
       function as close to the reset entry as possible to allow CoreUp event
       triggering. The SystemInitHook() weak function overloading is used in this
       application. */
    MCMGR_EarlyInit();
}

int main(void)
{
    /* Initialize MCMGR, install generic event handlers */
    MCMGR_Init();

    BOARD_InitPins();
    BOARD_InitBootPeripherals();
    BOARD_InitBootClocks();
    BOARD_InitDebugConsole();

	power_init();
	button_init();
    display_init();
	transputer_init();
    cooling_init();

	/* Init USB subsystem and LibUSBDevice */
	libusbdev_init();

	GPIO_PinWrite(BOARD_DEBUG_GPIO, BOARD_DEBUG_PORT, BOARD_DEBUG_PIN, true);
	GPIO_PinWrite(BOARD_DEBUG_GPIO, BOARD_DEBUG_PORT, BOARD_DEBUG_PIN, false);

	while (1U)
    {
		power_task();
		button_task();
		display_task();
		transputer_task();
	    cooling_task();

    	/* Sleep until next IRQ happens */
		__WFI();
    }
}

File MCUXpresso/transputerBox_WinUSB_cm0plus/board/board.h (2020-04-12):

/*
 * Copyright (c) 2016, Freescale Semiconductor, Inc.
 * Copyright 2016-2018 NXP
 * All rights reserved.
 *
 * SPDX-License-Identifier: BSD-3-Clause
 */

#ifndef _BOARD_H_
#define _BOARD_H_

#include "clock_config.h"
#include "fsl_common.h"
#include "fsl_gpio.h"

/*******************************************************************************
 * Definitions
 ******************************************************************************/
/*! @brief The board name */
#define BOARD_NAME "LPCXPRESSO54114"

#define BOARD_EXTCLKINRATE (0)

/*! @brief The UART to use for debug messages. */
#define BOARD_DEBUG_UART_TYPE kSerialPort_Uart
#define BOARD_DEBUG_UART_BASEADDR (uint32_t) USART0
#define BOARD_DEBUG_UART_INSTANCE 0U
#define BOARD_DEBUG_UART_CLK_FREQ CLOCK_GetFreq(kCLOCK_Flexcomm0)
#define BOARD_DEBUG_UART_CLK_ATTACH kFRO12M_to_FLEXCOMM0
#define BOARD_DEBUG_UART_RST kFC0_RST_SHIFT_RSTn
#define BOARD_UART_IRQ FLEXCOMM0_IRQn
#define BOARD_UART_IRQ_HANDLER FLEXCOMM0_IRQHandler

#define BOARD_DEBUG_UART_TYPE_CORE1 kSerialPort_Uart
#define BOARD_DEBUG_UART_BASEADDR_CORE1 (uint32_t) USART2
#define BOARD_DEBUG_UART_INSTANCE_CORE1 2U
#define BOARD_DEBUG_UART_CLK_FREQ_CORE1 CLOCK_GetFreq(kCLOCK_Flexcomm2)
#define BOARD_DEBUG_UART_CLK_ATTACH_CORE1 kFRO12M_to_FLEXCOMM2
#define BOARD_DEBUG_UART_RST_CORE1 kFC2_RST_SHIFT_RSTn
#define BOARD_UART_IRQ_CORE1 FLEXCOMM2_IRQn
#define BOARD_UART_IRQ_HANDLER_CORE1 FLEXCOMM2_IRQHandler

#define BOARD_DEBUG_SPI_CLK_FREQ 12000000

#ifndef BOARD_DEBUG_UART_BAUDRATE
#define BOARD_DEBUG_UART_BAUDRATE 115200
#endif /* BOARD_DEBUG_UART_BAUDRATE */

#ifndef BOARD_DEBUG_UART_BAUDRATE_CORE1
#define BOARD_DEBUG_UART_BAUDRATE_CORE1 115200
#endif /* BOARD_DEBUG_UART_BAUDRATE_CORE1 */

#ifndef BOARD_LED_RED_GPIO
#define BOARD_LED_RED_GPIO GPIO
#endif
#define BOARD_LED_RED_GPIO_PORT 0U
#ifndef BOARD_LED_RED_GPIO_PIN
#define BOARD_LED_RED_GPIO_PIN 29U
#endif
#ifndef BOARD_LED_GREEN_GPIO
#define BOARD_LED_GREEN_GPIO GPIO
#endif
#define BOARD_LED_GREEN_GPIO_PORT 1U
#ifndef BOARD_LED_GREEN_GPIO_PIN
#define BOARD_LED_GREEN_GPIO_PIN 10U
#endif
#ifndef BOARD_LED_BLUE_GPIO
#define BOARD_LED_BLUE_GPIO GPIO
#endif
#define BOARD_LED_BLUE_GPIO_PORT 1U
#ifndef BOARD_LED_BLUE_GPIO_PIN
#define BOARD_LED_BLUE_GPIO_PIN 9U
#endif

#ifndef BOARD_SW1_GPIO
#define BOARD_SW1_GPIO GPIO
#endif
#define BOARD_SW1_GPIO_PORT 0U
#ifndef BOARD_SW1_GPIO_PIN
#define BOARD_SW1_GPIO_PIN 24U
#endif
#define BOARD_SW1_NAME "SW1"
#define BOARD_SW3_IRQ PIN_INT0_IRQn
#define BOARD_SW3_IRQ_HANDLER PIN_INT0_IRQHandler

#ifndef BOARD_SW2_GPIO
#define BOARD_SW2_GPIO GPIO
#endif
#define BOARD_SW2_GPIO_PORT 0U
#ifndef BOARD_SW2_GPIO_PIN
#define BOARD_SW2_GPIO_PIN 31U
#endif
#define BOARD_SW2_NAME "SW2"
#define BOARD_SW3_IRQ PIN_INT0_IRQn
#define BOARD_SW3_IRQ_HANDLER PIN_INT0_IRQHandler

#ifndef BOARD_SW3_GPIO
#define BOARD_SW3_GPIO GPIO
#endif
#define BOARD_SW3_GPIO_PORT 0U
#ifndef BOARD_SW3_GPIO_PIN
#define BOARD_SW3_GPIO_PIN 4U
#endif
#define BOARD_SW3_NAME "SW3"
#define BOARD_SW3_IRQ PIN_INT0_IRQn
#define BOARD_SW3_IRQ_HANDLER PIN_INT0_IRQHandler
#define BOARD_SW3_GPIO_PININT_INDEX 0

#define BOARD_ARDUINO_INT_IRQ (GINT0_IRQn)
#define BOARD_ARDUINO_I2C_IRQ (FLEXCOMM4_IRQn)
#define BOARD_ARDUINO_I2C_INDEX (4)
/* Board led color mapping */
#define LOGIC_LED_ON 0U
#define LOGIC_LED_OFF 1U

#define LED_RED_INIT(output)                                                          \
    GPIO_PinInit(BOARD_LED_RED_GPIO, BOARD_LED_RED_GPIO_PORT, BOARD_LED_RED_GPIO_PIN, \
                 &(gpio_pin_config_t){kGPIO_DigitalOutput, (output)}) /*!< Enable target LED_RED */
#define LED_RED_ON()                                            \
    GPIO_PortClear(BOARD_LED_RED_GPIO, BOARD_LED_RED_GPIO_PORT, \
                   1U << BOARD_LED_RED_GPIO_PIN) /*!< Turn on target LED_RED */
#define LED_RED_OFF()                                         \
    GPIO_PortSet(BOARD_LED_RED_GPIO, BOARD_LED_RED_GPIO_PORT, \
                 1U << BOARD_LED_RED_GPIO_PIN) /*!< Turn off target LED_RED */
#define LED_RED_TOGGLE()                                         \
    GPIO_PortToggle(BOARD_LED_RED_GPIO, BOARD_LED_RED_GPIO_PORT, \
                    1U << BOARD_LED_RED_GPIO_PIN) /*!< Toggle on target LED_RED */
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

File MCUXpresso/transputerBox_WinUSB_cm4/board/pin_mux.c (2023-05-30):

/***********************************************************************************************************************
 * This file was generated by the MCUXpresso Config Tools. Any manual edits made to this file
 * will be overwritten if the respective MCUXpresso Config Tools is used to update this file.
 **********************************************************************************************************************/

/* clang-format off */
/*
 * TEXT BELOW IS USED AS SETTING FOR TOOLS *************************************
!!GlobalInfo
product: Pins v8.0
processor: LPC54114J256
package_id: LPC54114J256BD64
mcu_data: ksdk2_0
processor_version: 8.0.2
board: LPCXpresso54114
pin_labels:
- {pin_num: '3', pin_signal: PIO0_25/FC4_RTS_SCL_SSEL1/FC6_CTS_SDA_SSEL0/CTIMER0_CAP2/CTIMER1_CAP1, label: C012 Reset, identifier: C012_RESET}
- {pin_num: '2', pin_signal: PIO0_24/FC1_CTS_SDA_SSEL0/CTIMER0_CAP1/CTIMER0_MAT0, label: C012 Input Int, identifier: C012_INPUT_INT}
- {pin_num: '1', pin_signal: PIO0_23/FC1_RTS_SCL_SSEL1/CTIMER0_CAP0/UTICK_CAP1, label: C012 Output Int, identifier: C012_OUTPUT_INT}
- {pin_num: '4', pin_signal: PIO0_26/FC4_CTS_SDA_SSEL0/CTIMER0_CAP3}
- {pin_num: '7', pin_signal: PIO1_16/PDM0_DATA/CTIMER0_MAT0/CTIMER0_CAP0/FC7_RTS_SCL_SSEL1}
- {pin_num: '10', pin_signal: PIO1_17/MCLK/UTICK_CAP3}
- {pin_num: '11', pin_signal: PIO0_29/FC1_RXD_SDA_MOSI/SCT0_OUT2/CTIMER0_MAT3/CTIMER0_CAP1/CTIMER0_MAT1/ADC0_0, label: SDA1, identifier: SDA;SDA1}
- {pin_num: '12', pin_signal: PIO0_30/FC1_TXD_SCL_MISO/SCT0_OUT3/CTIMER0_MAT2/CTIMER0_CAP2/ADC0_1, label: SCL1, identifier: SCL;SCL1}
- {pin_num: '13', pin_signal: PIO0_31/PDM0_CLK/FC2_CTS_SDA_SSEL0/CTIMER2_CAP2/CTIMER0_CAP3/CTIMER0_MAT3/ADC0_2, label: Button, identifier: BUTTON}
- {pin_num: '14', pin_signal: PIO1_0/PDM0_DATA/FC2_RTS_SCL_SSEL1/CTIMER3_MAT1/CTIMER0_CAP0/ADC0_3, label: Fan Tacho 1, identifier: FAN_TACHO_1}
- {pin_num: '15', pin_signal: PIO1_1/SWO/SCT0_OUT4/FC5_SSEL2/FC4_TXD_SCL_MISO/ADC0_4, label: Fan Tacho 2, identifier: FAN_TACHO_2}
- {pin_num: '16', pin_signal: PIO1_2/MCLK/FC7_SSEL3/SCT0_OUT5/FC5_SSEL3/FC4_RXD_SDA_MOSI/ADC0_5}
- {pin_num: '17', pin_signal: PIO1_3/FC7_SSEL2/SCT0_OUT6/FC3_SCK/CTIMER0_CAP1/USB0_UP_LED/ADC0_6, label: LED, identifier: LED}
- {pin_num: '18', pin_signal: PIO1_4/PDM1_CLK/FC7_RTS_SCL_SSEL1/SCT0_OUT7/FC3_TXD_SCL_MISO/CTIMER0_MAT1/ADC0_7}
- {pin_num: '19', pin_signal: PIO1_5/PDM1_DATA/FC7_CTS_SDA_SSEL0/CTIMER1_CAP0/CTIMER1_MAT3/USB0_FRAME/ADC0_8}
- {pin_num: '26', pin_signal: PIO1_6/FC7_SCK/CTIMER1_CAP2/CTIMER1_MAT2/USB0_VBUS/ADC0_9}
- {pin_num: '27', pin_signal: PIO1_7/FC7_RXD_SDA_MOSI_DATA/CTIMER1_MAT2/CTIMER1_CAP2/ADC0_10}
- {pin_num: '28', pin_signal: PIO1_8/FC7_TXD_SCL_MISO_WS/CTIMER1_MAT3/CTIMER1_CAP3/ADC0_11}
- {pin_num: '29', pin_signal: PIO1_9/FC3_RXD_SDA_MOSI/CTIMER0_CAP2/USB0_UP_LED, label: Error, identifier: ERROR}
- {pin_num: '30', pin_signal: PIO1_10/FC6_TXD_SCL_MISO_WS/SCT0_OUT4/FC1_SCK/USB0_FRAME, label: Analyse, identifier: ANALYSE}
- {pin_num: '36', pin_signal: PIO0_2/FC0_CTS_SDA_SSEL0/FC2_SSEL3/CTIMER2_CAP1, label: Reset, identifier: RESET}
- {pin_num: '37', pin_signal: PIO0_3/FC0_RTS_SCL_SSEL1/FC2_SSEL2/CTIMER1_MAT3, label: Power On, identifier: PON}
- {pin_num: '38', pin_signal: PIO0_4/FC0_SCK/FC3_SSEL2/CTIMER0_CAP2}
- {pin_num: '39', pin_signal: PIO0_5/FC6_RXD_SDA_MOSI_DATA/SCT0_OUT6/CTIMER0_MAT0, label: Link Speed, identifier: LINK_SPEED}
- {pin_num: '40', pin_signal: PIO0_6/FC6_TXD_SCL_MISO_WS/CTIMER0_MAT1/UTICK_CAP0, label: Test, identifier: TEST}
- {pin_num: '41', pin_signal: PIO0_7/FC6_SCK/SCT0_OUT0/CTIMER0_MAT2/CTIMER0_CAP2, label: C012 D0, identifier: C012_D0}
- {pin_num: '42', pin_signal: PIO1_11/FC6_RTS_SCL_SSEL1/CTIMER1_CAP0/FC4_SCK/USB0_VBUS}
- {pin_num: '43', pin_signal: PIO0_8/FC2_RXD_SDA_MOSI/SCT0_OUT1/CTIMER0_MAT3, label: C012 D1, identifier: C012_D1}
- {pin_num: '44', pin_signal: PIO0_9/FC2_TXD_SCL_MISO/SCT0_OUT2/CTIMER3_CAP0/FC3_CTS_SDA_SSEL0, label: C012 D2, identifier: C012_D2}
- {pin_num: '45', pin_signal: PIO0_10/FC2_SCK/SCT0_OUT3/CTIMER3_MAT0, label: C012 D3, identifier: C012_D3}
- {pin_num: '46', pin_signal: PIO0_11/FC3_SCK/FC6_RXD_SDA_MOSI_DATA/CTIMER2_MAT1, label: C012 D4, identifier: C012_D4}
- {pin_num: '47', pin_signal: PIO0_12/FC3_RXD_SDA_MOSI/FC6_TXD_SCL_MISO_WS/CTIMER2_MAT3, label: C012 D5, identifier: C012_D5}
- {pin_num: '48', pin_signal: PIO0_13/FC3_TXD_SCL_MISO/SCT0_OUT4/CTIMER2_MAT0, label: C012 D6, identifier: C012_D6}
- {pin_num: '49', pin_signal: PIO0_14/FC3_CTS_SDA_SSEL0/SCT0_OUT5/CTIMER2_MAT1/FC1_SCK, label: C012 D7, identifier: C012_D7}
- {pin_num: '50', pin_signal: PIO0_15/FC3_RTS_SCL_SSEL1/SWO/CTIMER2_MAT2/FC4_SCK}
- {pin_num: '51', pin_signal: PIO1_12/FC5_RXD_SDA_MOSI/CTIMER1_MAT0/FC7_SCK/UTICK_CAP2, label: Speaker, identifier: SPEAKER}
- {pin_num: '52', pin_signal: PIO0_16/FC3_SSEL2/FC6_CTS_SDA_SSEL0/CTIMER3_MAT1/SWCLK}
- {pin_num: '53', pin_signal: PIO0_17/FC3_SSEL3/FC6_RTS_SCL_SSEL1/CTIMER3_MAT2/SWDIO}
- {pin_num: '54', pin_signal: PIO1_13/FC5_TXD_SCL_MISO/CTIMER1_MAT1/FC7_RXD_SDA_MOSI_DATA}
- {pin_num: '57', pin_signal: PIO1_14/FC2_RXD_SDA_MOSI/SCT0_OUT7/FC7_TXD_SCL_MISO_WS}
- {pin_num: '58', pin_signal: PIO0_18/FC5_TXD_SCL_MISO/SCT0_OUT0/CTIMER0_MAT0, label: C012 RS0, identifier: C012_RS0}
- {pin_num: '59', pin_signal: PIO0_19/FC5_SCK/SCT0_OUT1/CTIMER0_MAT1, label: C012 RS1, identifier: C012_RS1}
- {pin_num: '60', pin_signal: PIO0_20/FC5_RXD_SDA_MOSI/FC0_SCK/CTIMER3_CAP0, label: C012 RnotW, identifier: C012_RNOTW}
- {pin_num: '61', pin_signal: PIO0_21/CLKOUT/FC0_TXD_SCL_MISO/CTIMER3_MAT0, label: Debug Pin, identifier: DEBUG_PIN;DEBUG}
- {pin_num: '62', pin_signal: PIO1_15/PDM0_CLK/SCT0_OUT5/CTIMER1_CAP3/FC7_CTS_SDA_SSEL0}
- {pin_num: '63', pin_signal: PIO0_22/CLKIN/FC0_RXD_SDA_MOSI/CTIMER3_MAT3, label: C012 notCS, identifier: C012_NOTCS}
- {pin_num: '64', pin_signal: RESET}
 * BE CAREFUL MODIFYING THIS COMMENT - IT IS YAML SETTINGS FOR TOOLS ***********
 */
/* clang-format on */

#include "fsl_common.h"
#include "fsl_gpio.h"
#include "fsl_iocon.h"
#include "fsl_inputmux.h"
#include "pin_mux.h"

/* FUNCTION ************************************************************************************************************
 *
 * Function Name : BOARD_InitBootPins
 * Description   : Calls initialization functions.
 *
 * END ****************************************************************************************************************/
void BOARD_InitBootPins(void)
{
    BOARD_InitPins();
}
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

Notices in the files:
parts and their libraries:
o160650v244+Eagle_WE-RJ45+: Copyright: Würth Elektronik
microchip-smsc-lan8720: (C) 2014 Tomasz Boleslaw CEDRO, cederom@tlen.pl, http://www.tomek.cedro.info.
